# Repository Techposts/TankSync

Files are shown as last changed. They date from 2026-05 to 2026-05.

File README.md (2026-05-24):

# TankSync — reliable smart water monitoring






**Never worry about your water tank again.** A solar-powered sensor on the rooftop, a quiet hub on the wall, and smart water monitoring that keeps working — even when the internet doesn't. Long-range LoRa (RYLR998) to an ESP32 hub, local web UI, Home Assistant via HACS, optional cloud PWA. Open at the core.

<p align="center">
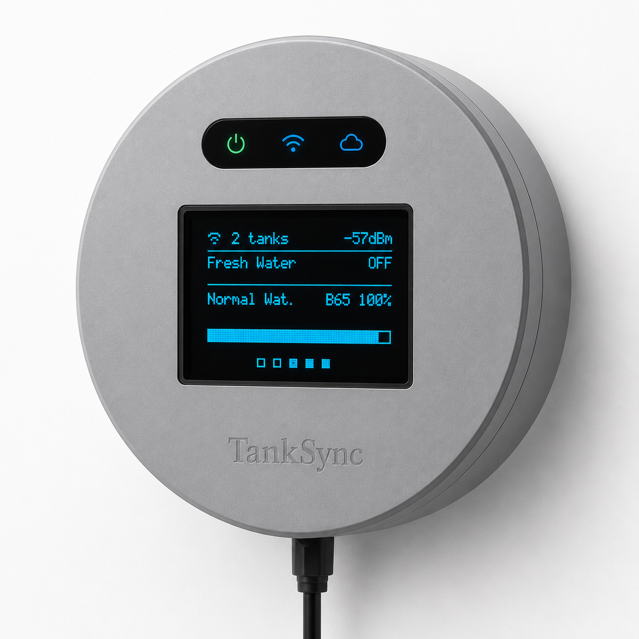
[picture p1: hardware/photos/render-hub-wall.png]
TankSync hub — wall-mounted, live OLED showing 2 tanks, status LEDs for power, WiFi, and cloud
  
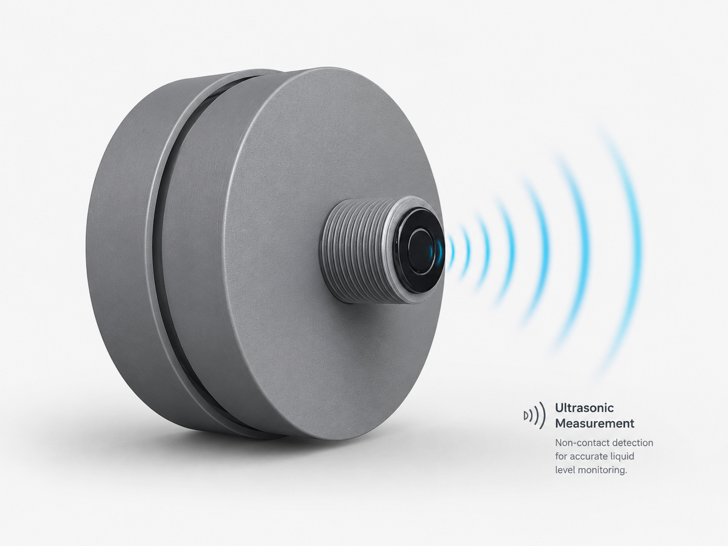
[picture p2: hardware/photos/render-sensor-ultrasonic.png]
TankSync solar tank sensor — side profile with ultrasonic measurement waves visualised
  
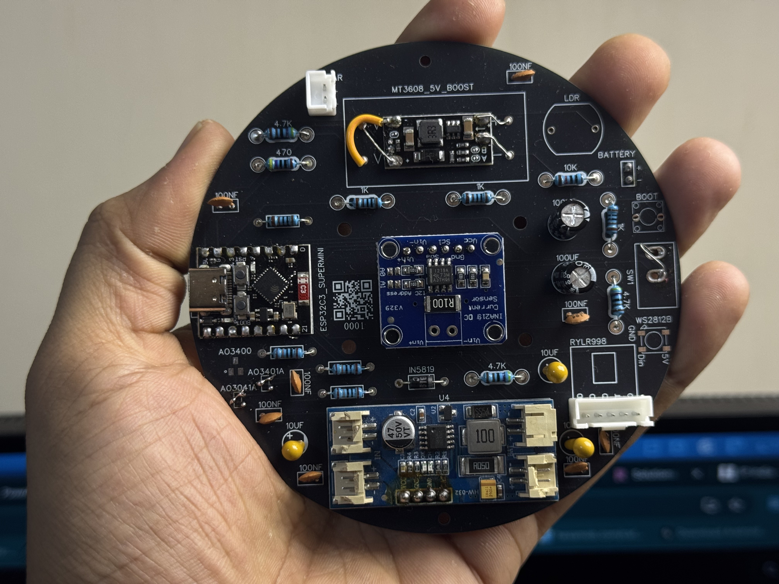
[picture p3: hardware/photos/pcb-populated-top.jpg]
Populated TX PCB — REV 2.2, May 2026 (open hardware)
  
</p>
<p align="center">
  <sub><em>The indoor hub (left), the solar tank sensor with non-contact ultrasonic measurement (centre), and the custom circular TX PCB (right) — current production hardware, REV 2.2 (May 2026), tested through Delhi summer at 45°C ambient.</em></sub>
</p>

## Try the in-browser flasher first

👉 **[tanksync.smartghar.org/firmware/](https://tanksync.smartghar.org/firmware/)**

No `esptool`, no Python, no CLI. Plug your board into USB, click Install, the browser does the flashing through WebSerial. Works on Chrome/Edge desktop. Takes ~45 seconds per board.

## Why TankSync — engineered to be reliable, not just smart

Most "smart tank" products treat the cloud as the product. TankSync treats **reliability** as the product — and the cloud as an optional layer of polish on top.

- **Works fully offline.** Hub keeps showing levels, lighting the LED ring, and beeping on overflow — even when your WiFi, your ISP, or our cloud is down. Local operation is the default; cloud is opt-in.
- **Long-range LoRa, no rooftop WiFi.** Sensor talks to the hub over 865 MHz LoRa — through concrete walls, between floors, across a property. Up to 5 km line-of-sight. The rooftop doesn't need WiFi. Ever.
- **Solar-powered transmitter.** Mounts on the tank lid. Charges in regular daylight, runs on a single 18650, deep-sleeps between readings. Months of autonomy. No wires to the tank.
- **Home Assistant native.** Auto-discovery via MQTT plus a dedicated [HACS integration](https://github.com/Techposts/smartghar-homeassistant) — every tank shows up as an HA device with live sensors, fill events, and editable settings.
- **Open at the core.** Firmware (AGPL-3.0), hardware (CC BY-SA 4.0), schematics, BOM, and flashing tools are all public. Self-host it. Fork it. Modify it. Audit it. No vendor lock-in.
- **Built for Indian realities.** Designed and tested through Delhi summer (45 °C ambient). UV-stabilised PETG, IP65 sealing, monsoon-ready. Engineered for terrace tanks, high-rise apartments, thick walls, and unreliable connectivity.

## Architecture

```
                    LoRa 865/915 MHz (up to 5 km, through walls)
                    ==============================================>
  TRANSMITTER                                          HUB (RECEIVER)
  ESP32-C3 SuperMini                                   ESP32 DevKit
  + JSN-SR04T Ultrasonic                               + RYLR998 LoRa
  + RYLR998 LoRa                                       + SH1106 OLED
  + 18650 + solar                                      + WS2812 LED ring
                                                       + WiFi (optional)
                                                          |
                                              +-----------+-----------+
                                              |                       |
                                       MQTT (TLS)              Local web UI
                                              |              192.168.x.x
                                    +---------+---------+
                                    |                   |
                              Home Assistant      Cloud dashboard
                              (HACS integration)  (optional, hosted)
```

## Hardware

| Component | Part | Approx cost (INR) |
|---|---|---|
| Receiver MCU | ESP32 DevKit v1 | ₹300–400 |
| Transmitter MCU | ESP32-C3 SuperMini | ₹200 |
| LoRa module | REYAX RYLR998 (×2) | ₹650 each |
| Ultrasonic sensor | JSN-SR04T (waterproof) | ₹350 |
| Display | SH1106 1.3" OLED I²C | ₹250 |
| Battery | Protected 18650 + holder | ₹200 |
| Solar charger | CN3791 MPPT module | ₹120 |
| Boost converter | MT3608 3.7 V → 5 V | ₹50 |

Total: **~₹3,800-5,200 per complete system** (one hub + one tank). Per-tank addition: ~₹1,500.

📐 **[Detailed wiring + power chains →](hardware/wiring.md)**
📋 **[Full BOM →](hardware/BOM.csv)**

## Quick start

### Option 1: Browser flasher (easiest — no install)

👉 **[tanksync.smartghar.org/firmware/](https://tanksync.smartghar.org/firmware/)**

Plug your board into a USB port, pick the right card (Receiver Hub or Transmitter), click Install. Done in ~45 sec.

### Option 2: esptool.py (CLI)

Download the latest `.bin` from [Releases](../../releases).

```bash
# Receiver (ESP32 DevKit)
esptool.py --chip esp32 -b 460800 write_flash 0x10000 tanksync-receiver-rx-vX.Y.Z.bin

# Transmitter (ESP32-C3 SuperMini)
esptool.py --chip esp32c3 -b 460800 write_flash 0x10000 tanksync-transmitter-tx-vX.Y.Z.bin
```

### Option 3: Build from source

Prerequisites: [ESP-IDF v5.4+](https://docs.espressif.com/projects/esp-idf/en/latest/esp32/get-started/)

```bash
# Receiver Hub
cd firmware/Receiver-ESP32-DevKit
idf.py build
idf.py -p /dev/ttyUSB0 flash

# Transmitter
cd firmware/Transmitter-IDF
idf.py set-target esp32c3
idf.py build
idf.py -p /dev/ttyACM0 flash
```

### First boot

1. **Hub** starts in AP mode → connect to `TankSync-XXXX` WiFi from your phone
2. Captive portal opens (or visit `192.168.4.1`)
3. Configure home WiFi + (optional) MQTT broker + LoRa settings

## What you'll use it through

Two surfaces — pick either, or both. They show the same data.

<p align="center">
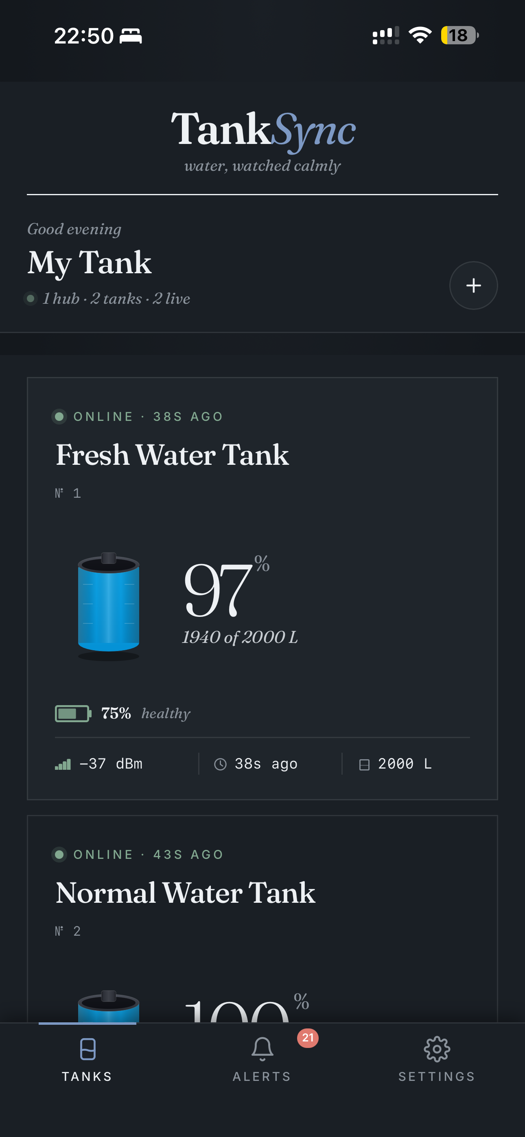
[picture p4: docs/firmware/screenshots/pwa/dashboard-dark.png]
TankSync PWA dashboard (phone)
  
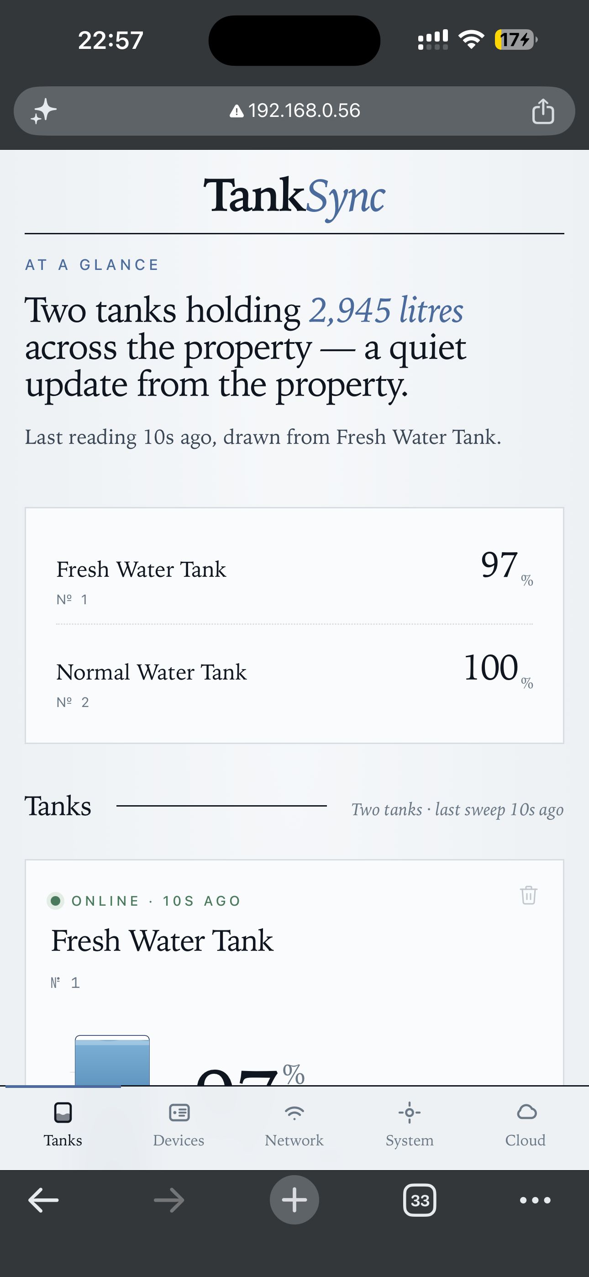
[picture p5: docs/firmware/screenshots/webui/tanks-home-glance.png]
Hub local web UI (any device on the same Wi-Fi)
  
</p>
<p align="center">
  <sub><em>Left: the PWA at <a href="https://tanksync.smartghar.org">tanksync.smartghar.org</a> — works from anywhere. Right: the hub's local web UI — works fully offline. Full walkthrough in the <a href="https://github.com/Techposts/TankSync/wiki">Wiki</a>.</em></sub>
</p>

4. **Transmitter** pairs over the air — hold its `BOOT` button for 2 sec, hub LED turns green when paired

## Photos of a real build

<p align="center">
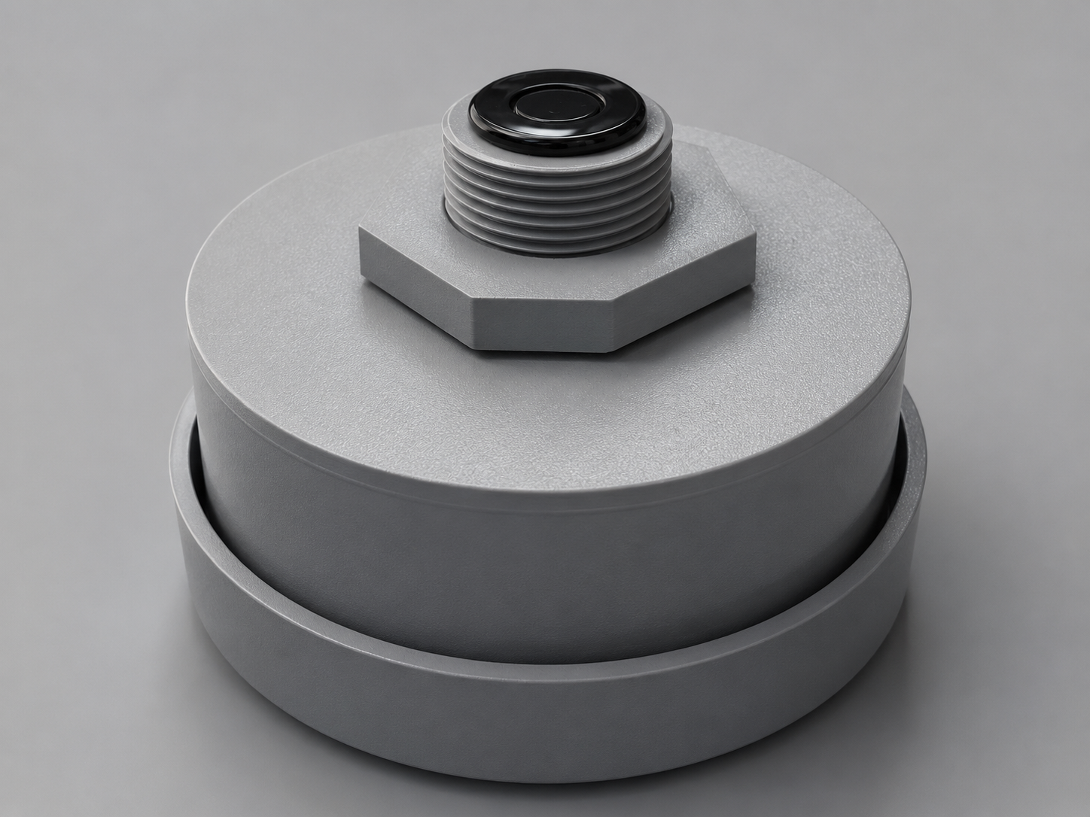
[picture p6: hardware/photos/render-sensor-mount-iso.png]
TankSync solar sensor — isometric render showing the BSP-threaded sensor boss + hex lock-nut
  
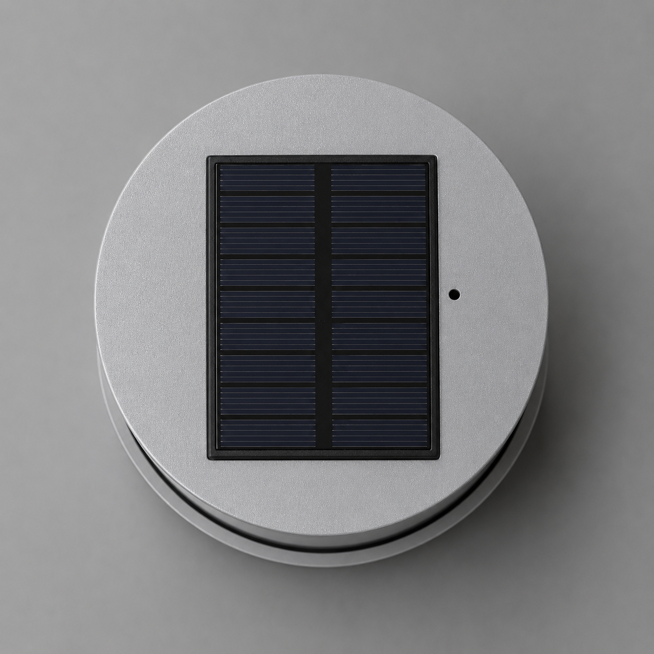
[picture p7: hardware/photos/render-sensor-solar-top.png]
TankSync solar sensor — top-down render showing the embedded solar panel
  
</p>
<p align="center">
  <sub><em>Renders of the production sensor — the threaded boss + hex lock-nut secure the sensor through a standard tank-lid hole; the solar panel sits flush on the case top.</em></sub>
</p>

<p align="center">
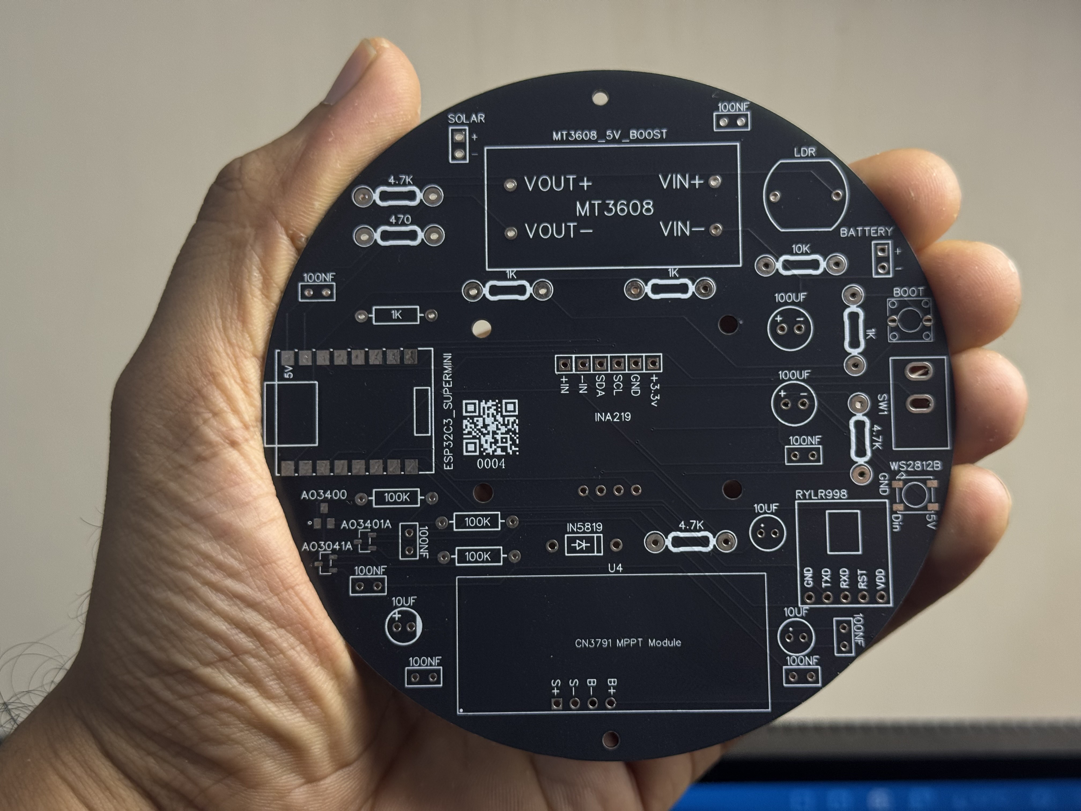
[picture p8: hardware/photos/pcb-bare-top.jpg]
Bare PCB, fresh from fab
  
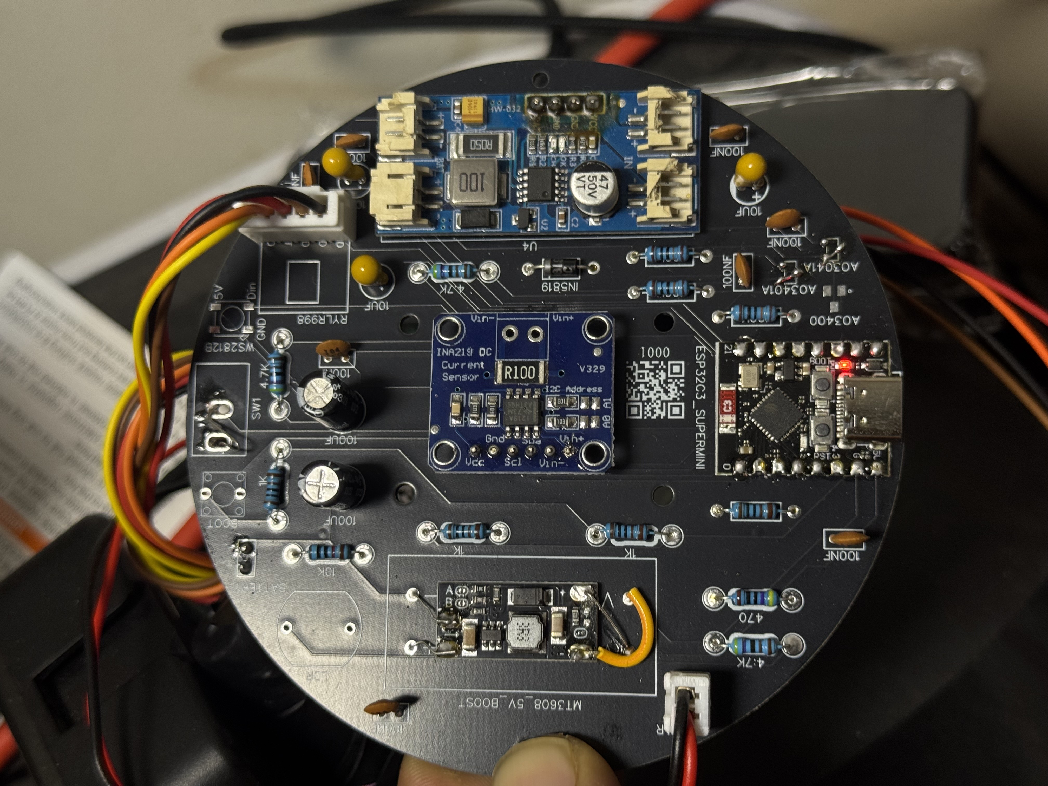
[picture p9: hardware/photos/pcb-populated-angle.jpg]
Populated PCB, angled view
  
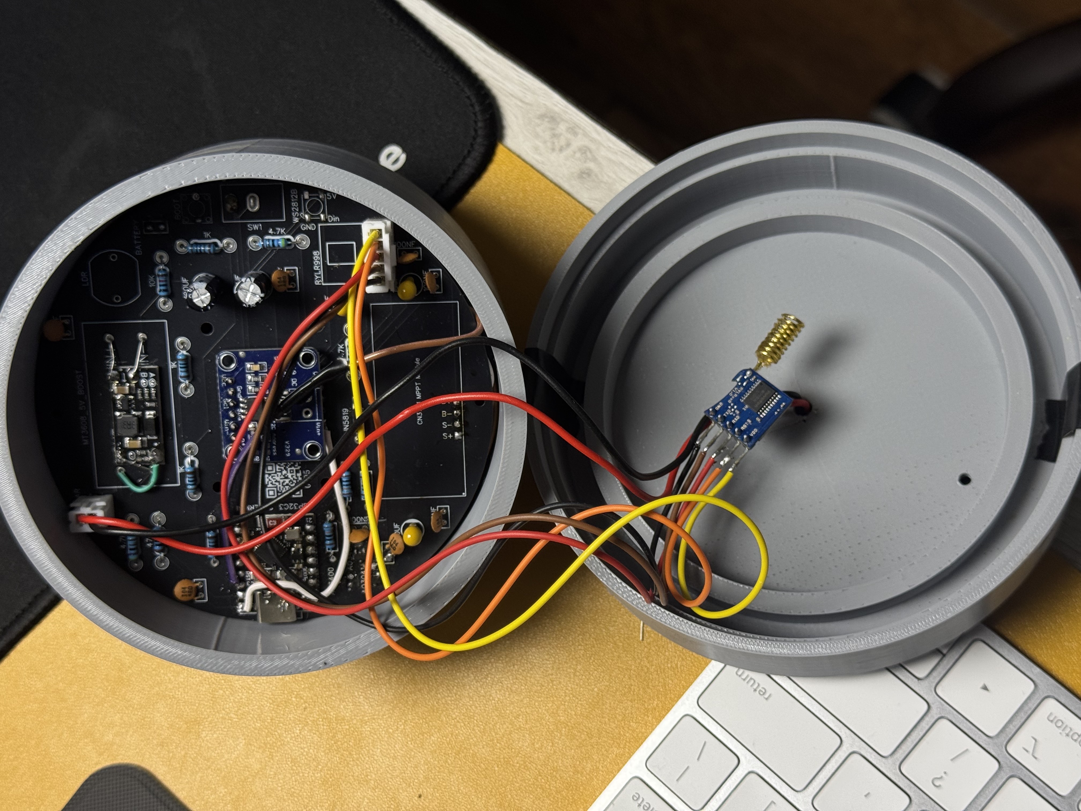
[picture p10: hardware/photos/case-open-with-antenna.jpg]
Opened case showing internals + antenna
  
</p>
<p align="center">
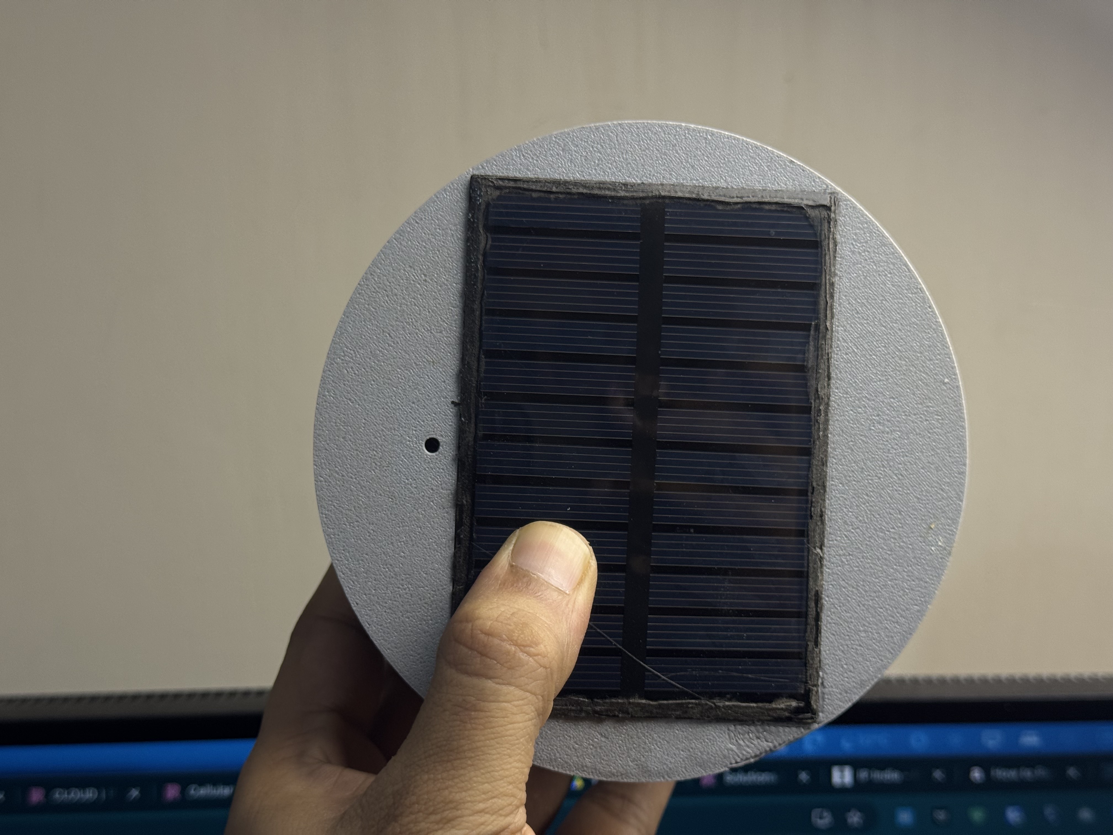
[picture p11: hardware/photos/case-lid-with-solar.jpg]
Lid with integrated solar panel pocket
  
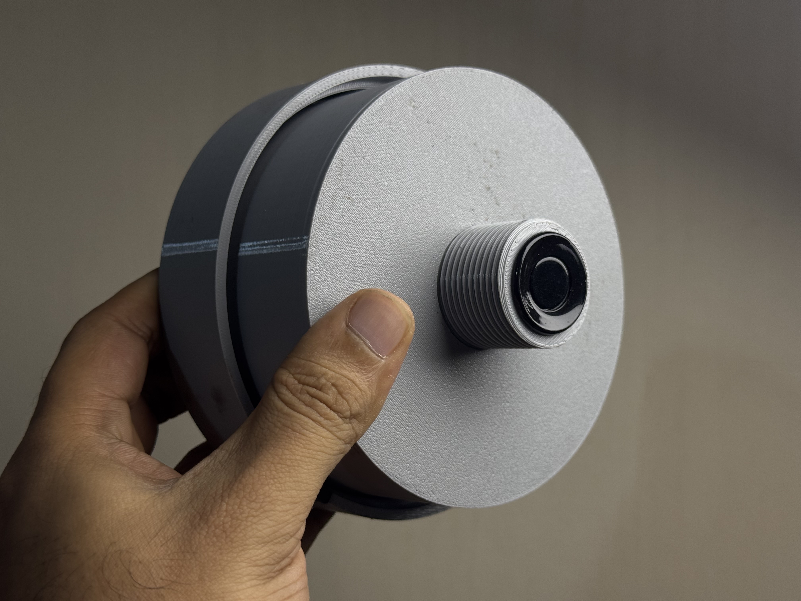
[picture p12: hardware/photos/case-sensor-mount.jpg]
BSP-threaded sensor mount on a test tank lid
  
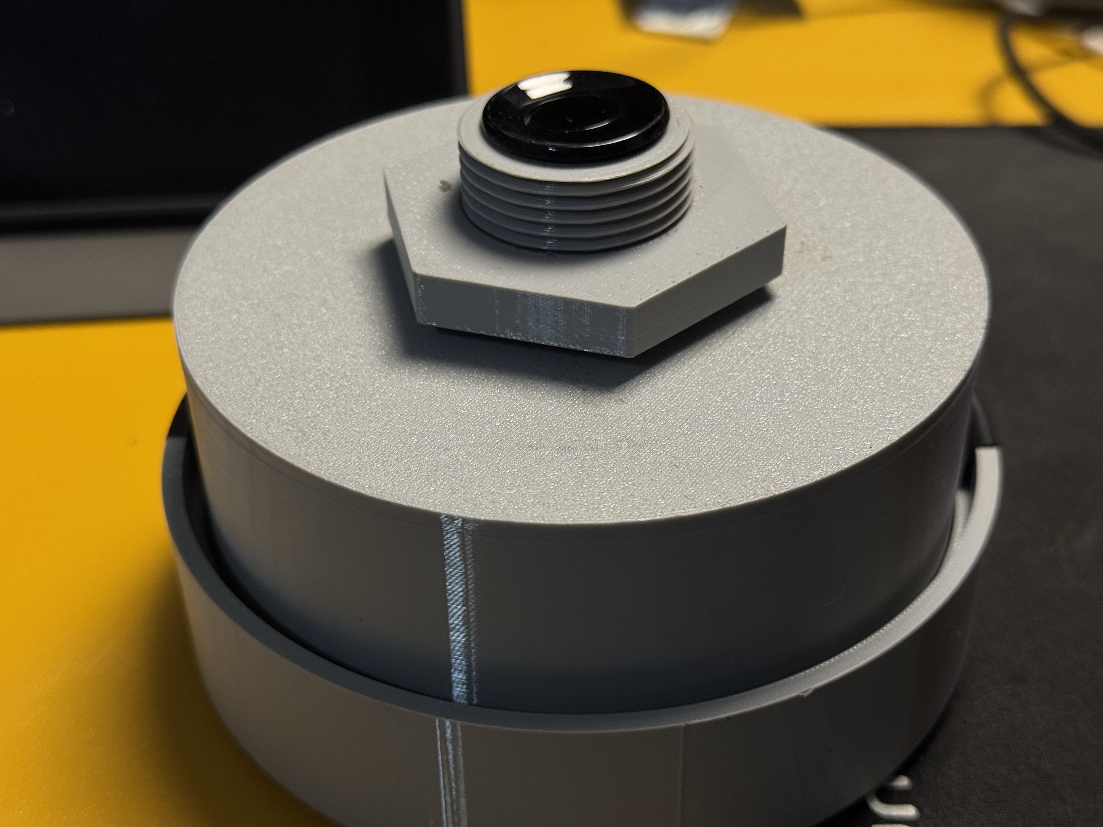
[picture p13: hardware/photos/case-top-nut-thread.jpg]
Close-up of the sensor-mount nut + thread
  
</p>

More photos + STL files for the case + schematics + 3D STEP models: **[hardware/](hardware/)**.

## Home Assistant integration

Two routes — pick whichever fits your setup:

1. **Native MQTT auto-discovery** — the hub publishes auto-discovery topics; tanks appear in HA as sensor entities with zero setup beyond pointing HA at the same broker. Read-only.
2. **HACS integration: SmartGhar** — full bidirectional control. Every tank is an HA device with grouped Sensors / Events / Configuration / Diagnostic entities, plus a hub device with buzzer + LED controls. **Capacity, sleep interval, samples-per-wake are editable from inside HA** and ride the same MQTT command channel as the PWA, so both stay in sync.

<p align="center">
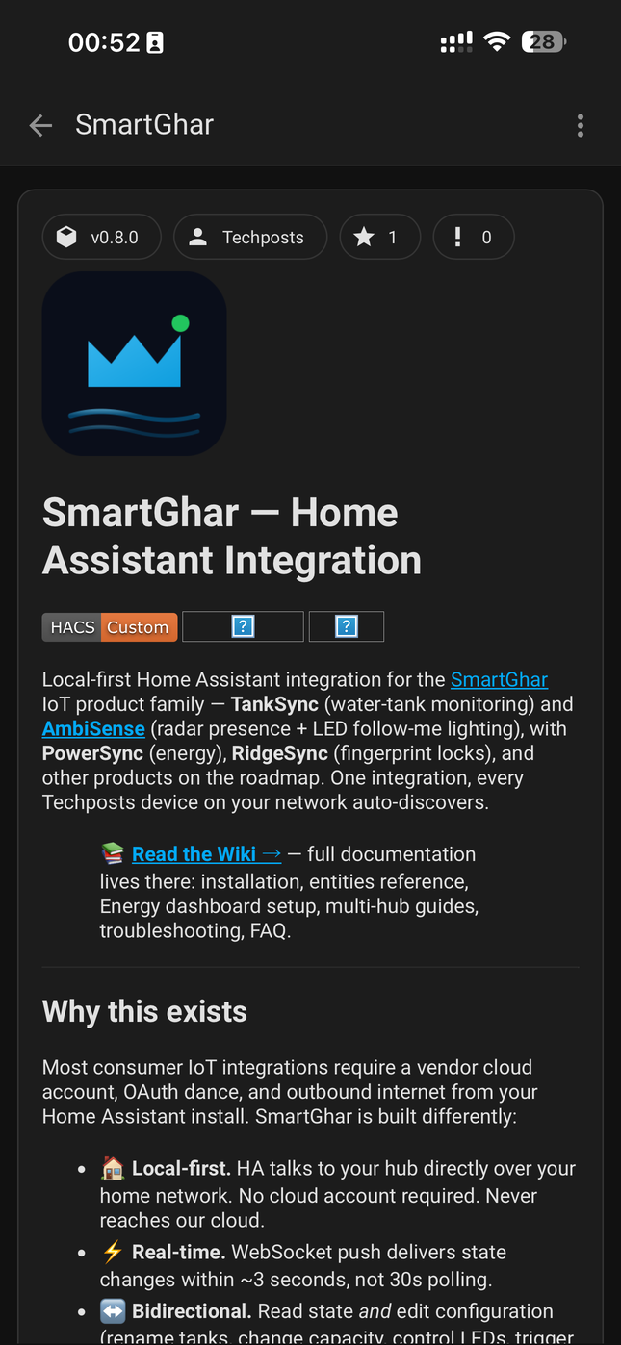
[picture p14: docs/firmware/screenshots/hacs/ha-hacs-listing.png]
HACS listing — SmartGhar v0.8.0
  
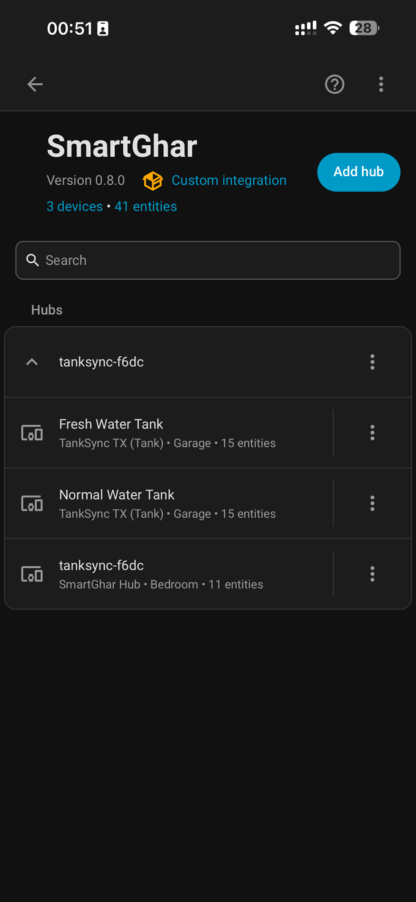
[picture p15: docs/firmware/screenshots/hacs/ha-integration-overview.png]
Integration overview — 3 devices, 41 entities
  
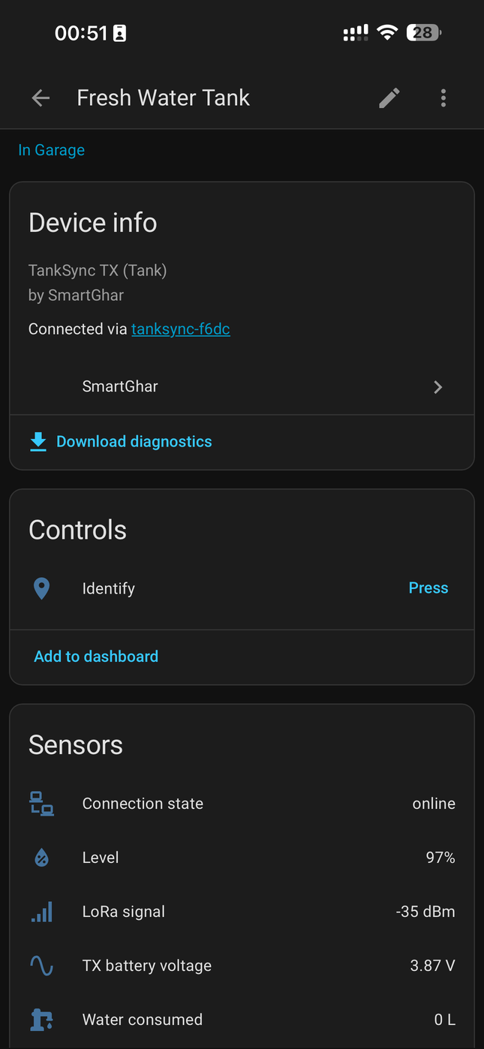
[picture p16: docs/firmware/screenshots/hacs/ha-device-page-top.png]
Tank device page — info + sensors
  
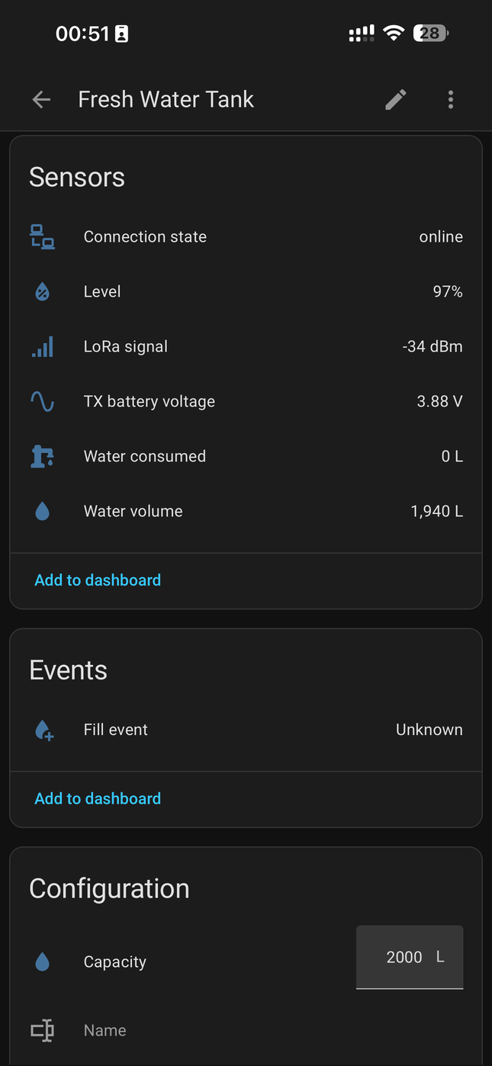
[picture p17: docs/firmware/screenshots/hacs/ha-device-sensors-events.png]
Sensors + Events + Configuration
  
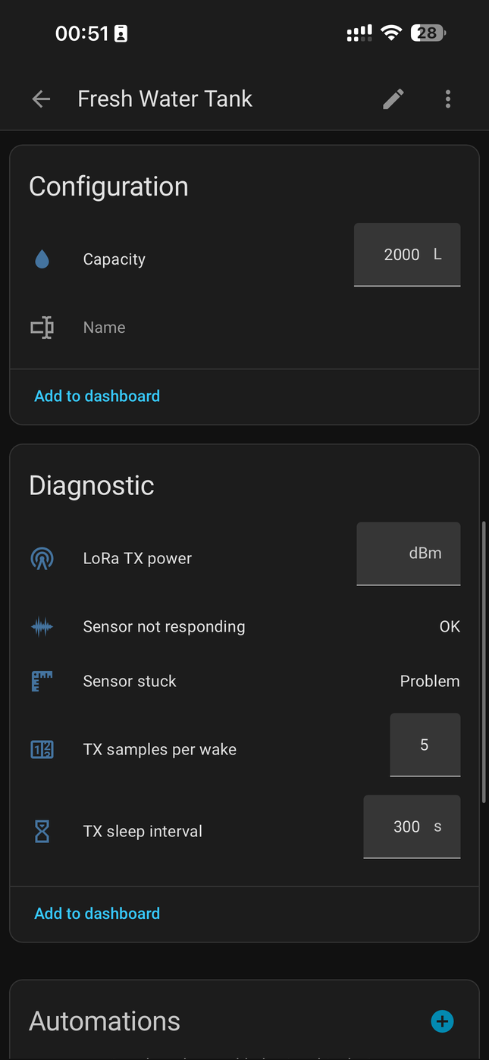
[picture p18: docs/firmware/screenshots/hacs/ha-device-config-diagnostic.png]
Configuration + Diagnostic — editable from HA
  
</p>

**HACS repo:** [github.com/Techposts/smartghar-homeassistant](https://github.com/Techposts/smartghar-homeassistant) · **Full setup + entity reference:** [HACS Integration wiki page](https://github.com/Techposts/TankSync/wiki/HACS-Integration)

## What's NOT in this repo (and why)

This is the open-source TankSync firmware + hardware mirror. The hosted cloud dashboard (PWA at [tanksync.smartghar.org](https://tanksync.smartghar.org)) is a separate **proprietary** product that adds:

- Remote access from anywhere (no port forwarding)
- Push notifications to your phone
- Multi-tank history + insights
- QR-code device linking
- Multi-hub fleet management for societies, farms, hotels

The firmware works fully **without** the cloud — local web UI on the hub gives you tank levels, settings, OTA updates, Home Assistant integration. Cloud is opt-in convenience, never a dependency.

## Licenses

| Component | License | What this means |
|---|---|---|
| Firmware (`firmware/`) | [AGPL-3.0](LICENSE) | Free for personal + community use. Commercial users who modify and distribute must also open-source their changes under AGPL. |
| Hardware (`hardware/`) | [CC BY-SA 4.0](hardware/LICENSE) | Attribution + ShareAlike. Build it, sell it, modify it — credit the source and share-alike. |
| HA Integration | [MIT](https://github.com/Techposts/smartghar-homeassistant/blob/main/LICENSE) (separate repo) | Frictionless for HA ecosystem. |

**Why AGPL on firmware?** It keeps TankSync open for hobbyists and HA users while preventing commercial vendors from repackaging the firmware into a closed product. If you want a non-AGPL commercial license for embedded use, reach out to the maintainer.

## Contributing

Issues and PRs welcome. Read the [wiring guide](hardware/wiring.md) before opening hardware-related issues.

## Author + brand

**Ravi Singh** ([@ravis1ngh on YouTube](https://www.youtube.com/@ravis1ngh)) — solo-building open-source home infrastructure in India under the **TechPosts Media** / **SmartGhar** banner. Design, firmware, hardware, PCB layouts, and 3D-printed enclosures — all done in-house.

**TankSync** is part of the **SmartGhar** ecosystem ([smartghar.org](https://smartghar.org)) — calm, local-first smart-home infrastructure engineered for real-world Indian deployments.

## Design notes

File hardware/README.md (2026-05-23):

# TankSync Hardware

> Open hardware reference for the **TankSync** LoRa water-tank monitor.
> All files in this `hardware/` tree are released under **CC-BY-SA 4.0** — you can build, modify, and resell them; derivative designs must stay open under the same license.
> Firmware is **AGPL-3.0** (see `firmware/`).

TankSync is two boards talking to each other:

| Board | Role | Power | Where it lives |
|---|---|---|---|
| **TX (Transmitter)** | Ultrasonic level sensor + LoRa uplink, one per tank | Solar + 18650 Li-ion | On / inside the tank lid |
| **RX (Receiver / Hub)** | LoRa gateway + Wi-Fi / MQTT bridge + OLED + LED strip | USB-C 5 V | Indoors, plugged into a wall adapter |

A single RX hub talks to up to **6 TX nodes** over 865 / 868 / 915 MHz LoRa (region-selectable in firmware). The RX publishes readings to a local MQTT broker or to the SmartGhar cloud — your choice.

---

## What's in this folder

| Path | What | Format |
|---|---|---|
| [`BOM.csv`](BOM.csv) | Complete bill of materials for both boards + the enclosure | CSV |
| [`pcb/`](pcb/) | Schematics (PNG + SVG), pin assignments, 3D STEP files, system block diagram | PNG / SVG / PDF / STEP |
| [`cases/circular-v1/`](cases/circular-v1/) | **Current** production case — circular PETG, integrated solar lid, BSP-threaded sensor mount | STL |
| [`cases/rectangular-v10/`](cases/rectangular-v10/) | **Legacy** v1.0 case — rectangular, older PCB form factor (kept for reference) | STL |
| [`photos/`](photos/) | Photos of the assembled PCB and finished case (9 images, see below) | JPG |

### Gallery (TX build)

| | |
|---|---|
| Bare PCB | Populated, top |
| Bare PCB, top side | Hand-soldered, top side |
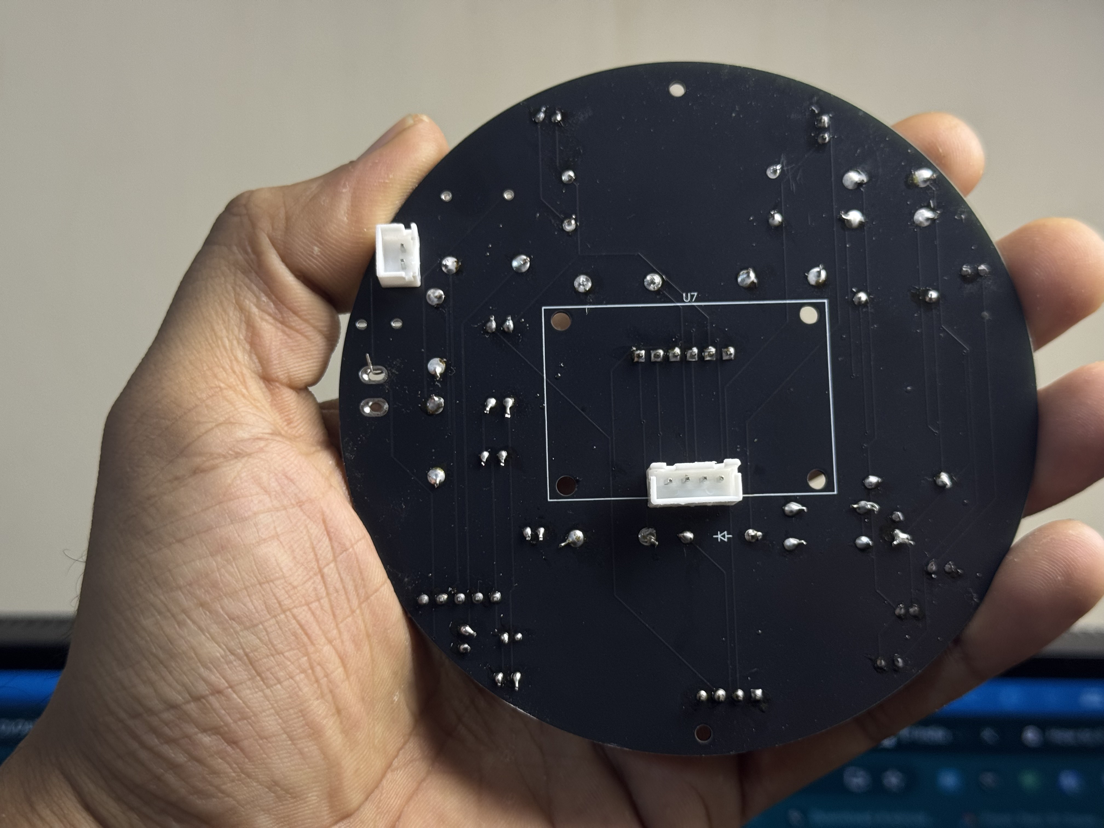
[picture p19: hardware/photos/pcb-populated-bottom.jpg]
Populated, bottom
|  | Populated, angle |
| Bottom side (passives + Schottky) | Angled view, modules stacked |
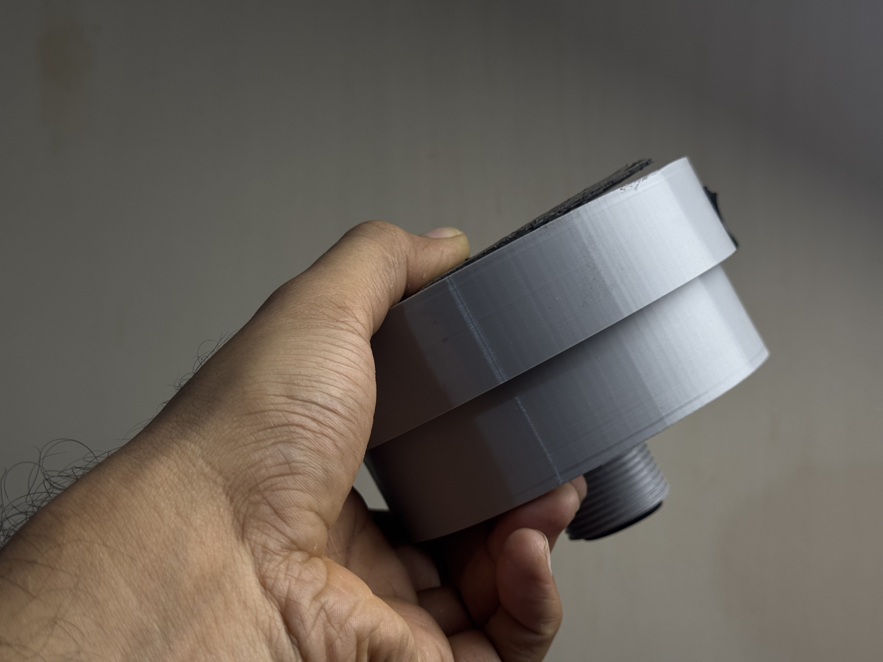
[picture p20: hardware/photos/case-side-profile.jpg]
Case side profile
| Lid with solar |  |
| Lid with integrated solar pocket | Closed assembly side view |
| Sensor mount | Top nut + thread |
| BSP boss in test tank lid | Close-up of nut + thread |
| Open with antenna | |
| Opened unit, SMA antenna variant | |

Each subfolder has its own `README.md` explaining what's inside and how to use it.

---

## Bird's-eye system diagram

```mermaid
flowchart LR
    TX[TX node<br/>solar + 18650] -->|LoRa 865 MHz| RX[RX hub<br/>USB-C]
    RX -->|Wi-Fi + MQTT| Broker[(MQTT broker<br/>local or cloud)]
    Broker --> HA[Home Assistant]
    Broker --> PWA[TankSync PWA]
```

All modules share a common ground. One TX per tank; one RX hub per property; up to 6 tanks per hub. Broker is either your local Mosquitto, or `mqtt.smartghar.org` if you use the free cloud tier.

---

## Quick start — I just want to build one

1. Print the case files from [`cases/circular-v1/`](cases/circular-v1/) (PETG, 0.2 mm, 30 % infill — see that folder's README).
2. Order parts from [`BOM.csv`](BOM.csv).
3. Get the PCBs fabbed from `pcb/rx-schematic.*` + `pcb/tx-schematic.*` (or send the project files to JLCPCB / PCBWay).
4. Solder, populate the BOM, then flash the firmware → easiest path is the **browser flasher** at [tanksync.smartghar.org/firmware](https://tanksync.smartghar.org/firmware) (Chrome / Edge desktop, USB-C cable, no toolchain install).
5. Power on the RX → connect to its `TankSync-Setup-XXXX` Wi-Fi AP → configure Wi-Fi + MQTT.
6. Hold the TX boot button 5 s → it joins the RX automatically via LoRa pairing mode.

The TankSync wiki has a step-by-step build guide: [github.com/Techposts/TankSync/wiki](https://github.com/Techposts/TankSync/wiki).

---

## Licensing

- **Firmware** (anything under `firmware/`) — AGPL-3.0
- **Hardware** (schematics, PCB layouts, STL cases, BOM, this folder) — CC-BY-SA 4.0
- **Brand** — "TankSync" and "SmartGhar" are trademarks of Ravi Singh / TechPosts Media; you can build and sell the open-hardware design but please don't use the brand names for commercial derivatives.

Patches welcome via pull request. If you ship a commercial product based on this design, the AGPL + CC-BY-SA terms require you to publish your modifications under the same license.

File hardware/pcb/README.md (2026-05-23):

# TankSync PCB Designs

Both boards were designed by **Ravi Singh** in EasyEDA — solo design work, no hardware team. The current production revision (**REV 2.2**, May 2026) has been **bench-tested at 45 °C ambient through Delhi summer** with no observable RYLR998 RSSI drift or boost-converter sag.

The TX is a **custom circular PCB** sized to drop straight into the [circular-v1 enclosure](../cases/circular-v1/). The RX is a **rectangular carrier** that sockets an ESP32 DevKit v1 (CP2102) module — no microcontroller redesign needed.

---

## Files in this folder

| File | What it is | When you need it |
|---|---|---|
| [`rx-schematic.png`](rx-schematic.png) / [`.svg`](rx-schematic.svg) | RX hub schematic | Read before populating the board |
| [`tx-schematic.png`](tx-schematic.png) / [`.svg`](tx-schematic.svg) | TX transmitter schematic | Read before populating the board |
| [`pin-assignments.md`](pin-assignments.md) / [`.pdf`](pin-assignments.pdf) | GPIO → function table for both boards | When firmware doesn't see a peripheral — check here first |
| [`system-block-diagram.pdf`](system-block-diagram.pdf) | One-page TX↔RX↔cloud overview | When explaining the system to someone new |
| [`rx-pcb-3d.step`](rx-pcb-3d.step) / [`tx-pcb-3d.step`](tx-pcb-3d.step) | 3D CAD models of the populated boards | If you're designing your own enclosure — import into Fusion / FreeCAD / OnShape |
| [`project-requirements.txt`](project-requirements.txt) | The original brief sent to PCBWay | Reference only — supersedes by the schematics + pin-assignments above |

---

## TX board (transmitter) — at a glance

- **MCU**: ESP32-C3 SuperMini (RISC-V, Wi-Fi + BLE, PCB antenna)
- **Radio**: REYAX RYLR998 LoRa module (UART AT-command, 865 / 868 / 915 MHz selectable)
- **Sensor**: JSN-SR04T / AJ-SR04M waterproof ultrasonic — connected via screw terminals so the sensor cable is field-installable
- **Power**: 18650 Li-ion + CN3791 MPPT solar charger + MT3608 3.3 V boost
- **Battery telemetry**: INA219 over I²C (current + voltage, signed) — replaced the older voltage-divider design in v1.0
- **Protection**: inline Schottky on the 18650 (+) rail; 1 k + 2 k divider on the 5 V ECHO line so the ECHO signal is safe for the C3's 3.3 V GPIO

### Power path

```mermaid
flowchart LR
    Panel[Solar panel<br/>~6V 1-2W] --> MPPT[CN3791 MPPT]
    MPPT --> Bat[18650 cell]
    Bat --> Boost[MT3608 boost]
    Boost --> C3[ESP32-C3 + RYLR998 + sensor]
```

All modules share a common ground. Vmpp tracking lands the panel near 4.5 V. The CN3791's BAT+ feeds the 18650 holder through an inline Schottky (SS14 / 1N5819) — destroyed two test boards before adding this.

### Signal path

```mermaid
flowchart LR
    C3[ESP32-C3<br/>SuperMini] <-->|UART1<br/>GPIO20/21| LoRa[RYLR998]
    C3 -->|TRIG<br/>GPIO4| Sens[JSN-SR04T]
    Sens -->|ECHO via 1k/2k div<br/>GPIO5| C3
    C3 <-->|I2C<br/>GPIO1/2| INA[INA219]
    C3 -->|WS2812 data<br/>GPIO7| LED[Status LED]
```

The full pin map is in [`pin-assignments.md`](pin-assignments.md) — that's the source of truth; if this diagram drifts, the table wins. Wire-by-wire detail also lives there.

---

## RX board (hub) — at a glance

- **MCU**: ESP32 DevKit v1 (Tensilica, Wi-Fi + BLE, USB-C onboard via CP2102)
- **Radio**: RYLR998 (same module as TX, same frequency, addresses differ)
- **Display**: 1.3" SH1106 OLED over I²C (status + Wi-Fi + IP + paired tanks)
- **LED strip**: WS2812B — user-selectable 2 / 8 / 24 LEDs, configured via the local web UI
- **Buzzer** (since rx-v2.8.0): active 3-pin piezo on GPIO 02 — audible nudges for low water, overflow, sensor errors
- **Power**: USB-C 5 V, 1 A nominal (5 W adapter is fine)

### Power path (RX)

```mermaid
flowchart LR
    USB[USB-C 5V] --> LDO[AMS1117-3.3]
    LDO --> ESP[ESP32 DevKit]
    LDO --> Lora[RYLR998 + OLED]
    USB -->|direct 5V<br/>+ 1000 µF cap| WS[WS2812B strip]
```

The WS2812B strip is on the **raw 5 V rail**, not the 3.3 V regulator output — a 24-LED ring at full white can draw >1 A, which would brown out the LDO. The 1000 µF inrush cap is critical.

### Signal path (RX)

```mermaid
flowchart LR
    ESP[ESP32 DevKit] <-->|UART2<br/>GPIO16/17| Lora[RYLR998]
    ESP <-->|I2C<br/>GPIO21/22| OLED[SH1106]
    ESP -->|WS2812 data<br/>GPIO13| WS[LED strip]
    ESP -->|Buzzer<br/>GPIO02| Buz[Piezo]
```

`GPIO 2` on the DevKit is taken by the **on-board LED**, which is why the **WS2812 data line is on GPIO 13**, not GPIO 2 — don't move it.

---

## Schematic reading tips (from review)

- The schematic PNG renders are correct but small; if you're hand-reviewing, open the SVG in a browser and zoom — the layer naming is preserved.
- The ECHO divider (TX) is on the PCB; do not omit it even if your sensor is rated for 3.3 V. JSN-SR04T variants in the wild differ on ECHO logic level, and the divider is cheap insurance.
- The I²C pull-ups on the TX board are populated as 4.7 kΩ. Some INA219 breakouts ship with their own pull-ups — if you use a breakout, remove or de-populate the on-PCB ones to avoid double pull-up.
- All decoupling caps (100 nF) belong **within 5 mm** of the IC power pin. The schematic shows them grouped for readability, but the layout enforces the distance.

---

## Critical things the firmware will refuse to boot without

1. **TX**: RYLR998 must answer `AT\r\n` at 115200 baud within 1.5 s. If wiring is reversed (TX↔RX swap), nothing pairs.
2. **RX**: SH1106 OLED must respond at I²C 0x3C. If absent or at 0x3D, the display stays blank but firmware otherwise runs — useful as a diagnostic.
3. **TX**: INA219 should answer at I²C 0x40. If absent, firmware falls back to voltage-divider battery monitoring on GPIO 0 (Variant A).

If you're hitting a boot loop, scope the UART RX line on either board first — most "the radio is dead" reports are reversed TX/RX wiring.

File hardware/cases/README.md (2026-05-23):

# TankSync Enclosures

Two case generations live here. **Print only the current revision unless you're explicitly building a legacy unit.**

| Folder | Status | PCB shape | Material | When to use |
|---|---|---|---|---|
| [`circular-v1/`](circular-v1/) | **Current — production** | Circular custom PCB | PETG | Always, for any new build |
| [`rectangular-v10/`](rectangular-v10/) | Legacy reference | Rectangular off-the-shelf carrier | PETG | Only if you already have v1.0 PCBs in inventory |

---

## Why two designs?

The original **rectangular v1.0** case was built around stacked off-the-shelf modules on a rectangular carrier — fine for the prototype, but the form factor wasn't ideal for the tank-lid mount, and the assembly involved many internal wires.

The **circular v1** is a ground-up redesign: a circular custom PCB sized to drop straight into the lid, with the ultrasonic sensor screw-mounted through a BSP-threaded boss, and an integrated solar-panel pocket on the top half. It was **tested through Delhi summer (45 °C ambient)** for thermal stability — the PETG holds shape, the panel doesn't delaminate, and the gasket compresses reliably.

The rectangular STL is kept here purely as reference for anyone who already fabbed those PCBs.

---

## Printing notes (shared across both designs)

- **Material**: PETG. *Not* PLA — sun + 45 °C summer = sag. *Not* ABS unless you've got an enclosure printer with good ventilation. ASA also works.
- **Layer height**: 0.2 mm structural / 0.16 mm cosmetic
- **Infill**: 30 % gyroid (good stiffness-to-weight + survives compression on screw-down)
- **Walls**: 4 perimeters minimum — strength matters more than print speed for outdoor parts
- **Supports**: needed on the sensor screw and (for circular-v1) the lid-with-solar piece. See per-design README for tree-vs-grid hint.
- **Brim**: 5 mm — PETG warp is real on first layer if the bed is below 80 °C
- **Bed**: 80–90 °C; nozzle 240–250 °C
- **Outdoor seal**: every case is designed to clamp a 1–2 mm EPDM gasket between lid and body. The screw torque does the sealing — don't skip the gasket if the tank is outdoors.

See `../../docs/hardware/printing-guide.md` (work in progress) for tested slicer profiles.

---

## Choosing between PETG colours

Black PETG runs hotter under sun (measured ~5 °C above ambient). The TX has thermal margin — 45 °C ambient + 5 °C tint + 5 °C internal dissipation = within the 18650's 65 °C derating. But if you live somewhere genuinely hot (Rajasthan summer, north Australia), **print white or light-grey** for the lid. The base can stay any colour you like.

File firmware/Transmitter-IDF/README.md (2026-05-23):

# TankSync Transmitter (ESP-IDF v2)

ESP32-C3 SuperMini battery-powered transmitter for the LoRa Water Tank Monitor.

## Hardware

- **MCU**: ESP32-C3 SuperMini (4MB flash, RISC-V single-core)
- **LoRa**: RYLR998 module (868/915 MHz)
- **Sensor**: AJ-SR04M ultrasonic distance sensor
- **Power**: LiPo battery with deep sleep (~300s cycle)

### Pin Configuration

| Function | GPIO | Notes |
|---|---|---|
| LoRa TX | 21 | UART1 TX to RYLR998 RXD |
| LoRa RX | 20 | UART1 RX from RYLR998 TXD |
| LED | 8 | On-board LED (C3 SuperMini) |
| Button | 9 | Boot button (active low, internal pullup) |
| Ultrasonic TRIG | 4 | AJ-SR04M trigger |
| Ultrasonic ECHO | 5 | AJ-SR04M echo |
| Battery ADC | 0 | Voltage divider (1:2 ratio) |

## Boot Window

On **power-on or reset** (NOT timer wake), the TX opens a 10-second boot window. LED blinks at 1Hz. Hold the button for:

| Hold Duration | Action | LED Feedback |
|---|---|---|
| 2 seconds | **Pairing mode** — broadcasts PAIR_REQ via LoRa | 6 rapid flashes |
| 5 seconds | **Diagnostic mode** — prints system info to serial | Steady on |
| 8 seconds | **WiFi OTA mode** — creates WiFi AP for firmware update | 10 rapid flashes |

Timer wakes from deep sleep skip the boot window entirely (battery savings).

## Firmware Update Methods

### Method 1: WiFi AP OTA (Recommended for deployed devices)

1. Press **reset** on the transmitter
2. During the 10s boot window, **hold the button for 8 seconds**
3. LED flashes rapidly to confirm — TX creates WiFi AP: **`TankSync-Update`**
4. Connect your phone/laptop to the `TankSync-Update` WiFi network (open, no password)
5. Open a browser and go to **`http://192.168.4.1`**
6. The web page shows:
   - **Device Info** — current firmware version, LoRa address, sleep/sample settings
   - **Settings** — edit sleep interval and sample count, save directly to NVS
   - **Firmware Update** — select a `.bin` file and upload with progress bar
7. After successful upload, the TX verifies the binary and reboots
8. If no activity for 5 minutes, TX auto-reboots to normal mode

**Status**: WiFi AP starts and serves the page. OTA upload handler is implemented. Needs end-to-end testing.

### Method 2: LoRa OTA (Experimental — pushed from receiver)

The receiver can push firmware updates to the transmitter over LoRa during the TX's downlink window.

**Protocol**:
1. Receiver stages TX firmware binary on SPIFFS via web UI
2. When TX wakes and sends TANK data, receiver sends `OTA_START:<size>` (3x for reliability)
3. Both sides switch to SF7/500kHz for faster chunk streaming
4. TX sends `OTA_READY` (3x), enters chunk receive loop
5. Receiver streams 100-byte chunks as hex-encoded `OTA_DATA:<offset>:<hex>`
6. TX ACKs each chunk with `OTA_ACK:<next_offset>`
7. After all chunks: `OTA_END` / `OTA_DONE` exchange, TX reboots

**Status**: Partially working. Chunks are delivered at SF7/500kHz (~260ms per chunk, 23x faster than SF9/125kHz). However, ~40% ACK packet loss causes the transfer to stall after 6-30 chunks. The half-duplex nature of LoRa means the receiver can't receive ACKs while transmitting chunks.

**Known Issues**:
- ACK reliability: TX sends OTA_ACK but receiver misses ~40-50% due to half-duplex timing
- OTA_READY often lost (worked around with soft wait + proceed anyway)
- At SF9/125kHz, chunk airtime is 1050ms creating a large half-duplex blind window
- At SF7/500kHz, airtime drops to ~45ms but packet loss persists at lower rates

**Potential fixes** (contributions welcome):
- Blast mode: skip per-chunk ACK, stream all chunks with fixed delay, verify at end
- Adaptive retry with exponential backoff
- Reduce chunk size to minimize airtime
- Use address 0 (broadcast) for chunks to bypass address filtering edge cases

### Method 3: USB Serial (Development only)

```bash
cd Transmitter-IDF
. ~/esp/esp-idf/export.sh
idf.py -p /dev/cu.usbmodem12201 flash
```

## Building

```bash
cd Transmitter-IDF
. ~/esp/esp-idf/export.sh    # or wherever your ESP-IDF is installed
idf.py set-target esp32c3
idf.py build
```

**Important**: After `set-target`, the sdkconfig may re-enable WiFi. The custom partition table and flash size are set in `sdkconfig.defaults`.

## Version Management

Two version strings must be kept in sync:
- `main/config.h` → `FIRMWARE_VERSION` (used in TANK packets and logs)
- `CMakeLists.txt` → `PROJECT_VER` (embedded in binary `esp_app_desc_t`, read by receiver for OTA display)

## Partition Table

```
nvs,      data, nvs,      0x9000,   0x5000
otadata,  data, ota,      0xe000,   0x2000
app0,     app,  ota_0,    0x10000,  0x1D0000  (1.8MB)
app1,     app,  ota_1,    0x1E0000, 0x1D0000  (1.8MB)
coredump, data, coredump, 0x3B0000, 0x10000
```

Current firmware size: ~860KB (with WiFi AP OTA) / ~263KB (without). Both fit within the 1.8MB partition.

## NVS Keys

| Namespace | Key | Type | Description |
|---|-----|---|---|
| `system` | `sleep_s` | u32 | Sleep interval in seconds (default: 300) |
| `system` | `samples` | u8 | Sensor samples per reading (default: 5) |
| `lora` | `my_addr` | u16 | Device LoRa address (set during pairing) |
| `lora` | `rx_addr` | u16 | Receiver's LoRa address (default: 2) |
| `lora` | `freq` | u32 | LoRa frequency in Hz |
| `lora` | `netid` | u8 | Network ID |
| `lora` | `sf` | u8 | Spreading factor (7-12) |
| `lora` | `bw` | u8 | Bandwidth (7=125kHz, 8=250kHz, 9=500kHz) |
| `lora` | `pwr` | u8 | TX power (0-22 dBm) |

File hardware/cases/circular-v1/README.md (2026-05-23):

# Circular v1 Enclosure — Current Production

Production case as of **May 2026**. Designed for the circular custom PCB documented in [`../../pcb/`](../../pcb/). Tested through Delhi summer (45 °C ambient) — PETG holds shape, integrated solar pocket doesn't delaminate, EPDM gasket compresses reliably for IP65 sealing.

---

## STL files

| File | What it is | Print orientation |
|---|---|---|
| [`base-holder.stl`](base-holder.stl) | Bottom shell — holds the PCB + 18650 holder | Flat side down, no supports inside the cavity |
| [`top-with-solar.stl`](top-with-solar.stl) | Top lid with integrated solar-panel pocket | Solar pocket facing up, **tree supports** on the underside of the lip |
| [`sensor-screw.stl`](sensor-screw.stl) | BSP-threaded boss the JSN-SR04T screws through | Threads up; supports on the gland-side flange |
| [`nut.stl`](nut.stl) | Locking nut that mates with the sensor-screw boss from inside the tank lid | Flat down, no supports |

Print all four for a complete unit.

---

## Bill of additional parts

In addition to the PCB BOM ([`../../BOM.csv`](../../BOM.csv)):

| Item | Spec | Where it goes |
|---|---|---|
| Solar panel | 6 V, 1–2 W, 60–80 mm matching the lid pocket | Sits in the top-with-solar pocket; wires through small grommet |
| EPDM gasket | 1–2 mm × 60 mm OD circular, NBR also OK | Between base and lid |
| M3 stainless screws | 4×, 12 mm length | Lid → base, through gasket |
| M3 stainless threaded inserts (optional) | Heat-set, 4× | Base — for stronger repeated open/close |
| Cable gland | M12 PA66 IP65, 4–6 mm cable range | Bottom of base — sensor cable exit |
| BSP thread (sensor mount) | Matches `sensor-screw.stl` threads | Field-drilled into the tank lid |

---

## Assembly sequence (TLDR)

1. Heat-set M3 inserts into the four corners of `base-holder.stl` (if using).
2. Drop the populated TX PCB into the base; align mount holes; tape the 18650 holder in place.
3. Feed the sensor cable through the cable gland from outside, leaving slack inside. Screw-terminal both ends to the PCB.
4. Mount the panel into the lid pocket; thread its wires through the small grommet; solder to the PCB's panel input.
5. Place the EPDM gasket on the base rim. Screw the lid down with the four M3 stainless screws — moderate torque (~1 Nm). The gasket compresses to ~50 % thickness.
6. The `sensor-screw.stl` + `nut.stl` mount on the **tank lid itself**, with the JSN-SR04T head facing down into the tank. Apply Teflon tape on the BSP threads for water seal.

A photo-by-photo build guide is in the wiki: [github.com/Techposts/TankSync/wiki/Hardware-Build](https://github.com/Techposts/TankSync/wiki/Hardware-Build).

---

## Design notes

- The lid solar pocket is **slightly oversize** to allow a 1 mm silicone bead around the panel for UV sealing. Don't pour epoxy — it traps heat against the panel.
- The sensor-screw boss is intentionally tall (~20 mm) so the JSN-SR04T transducer head sits clear of the tank lid's internal surface. Lid-touching sensors give phantom echoes from the lid material.
- The PETG print is rated for outdoor use, but **direct UV will yellow it over years**. If you care about aesthetics long-term, add a 1 mm clear-coat or use ASA.
- IP65 was the design target — tested with light rain + hose spray. Not tested under submersion (and the tank shouldn't ever submerge the TX anyway).

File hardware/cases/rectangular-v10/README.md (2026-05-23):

# Rectangular v1.0 Enclosure — Legacy

Original prototype case used during TankSync v1.0. **Kept here for reference only.** New builds should use [`../circular-v1/`](../circular-v1/) — that's the current production design.

You only want this folder if:

- You already fabbed rectangular v1.0 PCBs and have inventory to use up, or
- You're studying the design evolution for your own project.

---

## STL files

| File | What it is |
|---|---|
| [`main-body.stl`](main-body.stl) | Bottom shell of the original rectangular enclosure |
| [`top-lid.stl`](top-lid.stl) | Top lid (no solar pocket — this design had an external panel) |
| [`tpu-gasket.stl`](tpu-gasket.stl) | Printable TPU gasket (alternative to a die-cut EPDM gasket) |
| [`sensor-screw.stl`](sensor-screw.stl) | Sensor mount — matches the v1.0 sensor-cable layout |
| [`bolt-screw.stl`](bolt-screw.stl) | Captive screw used to clamp lid to body in the v1.0 design |

---

## Why it's legacy

The rectangular v1.0 case worked, but had drawbacks the circular v1 redesign solved:

1. **Form factor** — rectangular footprint doesn't match how most tank lids are shaped (round threaded openings), so mounting required adapters.
2. **Solar panel** — external, wired in through a grommet. Two more failure points (UV-aging cable + grommet seal).
3. **Assembly time** — more internal wiring (stacked modules on a rectangular carrier, vs the circular custom PCB which integrates everything).
4. **Print time** — larger XY footprint means longer prints.

The TPU printable gasket worked fine but most builders switched to die-cut EPDM (more consistent compression, cheaper at >10 units).

For any new build use [`../circular-v1/`](../circular-v1/).

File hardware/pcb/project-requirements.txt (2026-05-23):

PROJECT TITLE
TankSync v1.0 — Solar LoRa water-tank monitor: outdoor TX + indoor RX hub for Indian homes

PROJECT REQUIREMENTS

A two-board IoT product. Hardware bench-validated on dev kits with working open-source firmware (github.com/Techposts/tanksync). I need PCBWay to convert proven pin assignments and bench wiring into manufacturable PCBs + matching enclosures + sample units.

A) TX (Tank Transmitter) — outdoor, solar-powered, mounts on overhead/sump tanks. Reads water level via ultrasonic sensor; sends readings via LoRa to indoor hub. Deep-sleeps between wakes for battery life.

B) RX (Receiver / Hub) — indoor, USB-C powered. Receives LoRa from up to 6 paired TX, drives OLED + LED ring, bridges to cloud via WiFi/MQTT, hosts local web UI.

----------------------------------------------------------------------
1. PCB DESIGN REQUIREMENTS
----------------------------------------------------------------------

FUNCTIONAL REQUIREMENTS

TX Board:
- Read distance via ultrasonic sensor (JSN-SR04T / AJ-SR04M, waterproof)
- Sense battery + solar power via INA219 (I2C) and ADC voltage divider (variant)
- Charge 18650 Li-ion from solar via CN3791 MPPT + boost converter to 3.3V
- Communicate with RX over LoRa (RYLR998 module, UART)
- Deep-sleep between wake cycles (default 60s, configurable to 5–60 min)
- Status LED + tactile BOOT button (5s hold = AP mode for re-pairing)

RX Board:
- Receive LoRa packets from up to 6 TX units
- Drive 1.3" SH1106 OLED (I2C) for live tank levels
- Drive WS2812B LED chain (2 / 8 / 24 LEDs) for ambient indication
- Connect to home WiFi, publish telemetry to MQTT broker
- Host a local HTTP server for configuration (port 80)
- USB-C input, BOOT/RESET buttons accessible

INPUT/OUTPUT INTERFACES

TX:
- Screw terminal (2-pin) for ultrasonic sensor cable (field-installable, NOT pre-crimped at factory — sensor cable length varies by tank)
- Screw terminal or barrel jack (2-pin) for solar panel input
- 18650 battery holder
- Tactile BOOT + RESET buttons through enclosure window
- Status LED visible through enclosure window
- USB-C for development flashing

RX:
- USB-C for power + flashing
- 3-pin connector for WS2812B LED strip (5V, GND, DATA)
- 4-pin I2C header for SH1106 OLED (3.3V, GND, SDA, SCL) — display can be onboard or off-board
- BOOT + RESET tactile buttons accessible
- RYLR998 LoRa module on header (SMA antenna optional, PCB-edge whip default)

PERFORMANCE REQUIREMENTS

TX:
- MCU: ESP32-C3 SuperMini (RISC-V, 160 MHz, integrated WiFi/BT, PCB antenna)
- LoRa link: 865 MHz (India ISM band) at 22 dBm, SF7-12 configurable
- Active current: <5 mA during a wake cycle (~1.5 s of sensor read + LoRa transmit)
- Deep sleep current: <50 µA average over 60s sleep cycle
- Sensor accuracy: ±1 cm at 30 cm – 4 m range (JSN-SR04T spec)
- Battery life target: >12 months in clean Indian sun on a 1.5W panel

RX:
- MCU: ESP32 DevKit (Tensilica, 240 MHz, WiFi + BT)
- LoRa: same as TX
- I2C: 100 kHz standard mode (OLED + future I2C peripherals)
- WiFi: 2.4 GHz station mode + AP mode (for setup)
- LED refresh: 30 Hz typical, supports inrush spikes up to 1 A briefly

DIMENSIONS AND PHYSICAL SPECIFICATIONS

TX board: target ~50 × 50 mm, 1.6 mm FR-4, 4 corner mounting holes (M2.5).
RX board: target ~70 × 50 mm, 1.6 mm FR-4, 4 corner mounting holes (M2.5).
Both boards must fit inside their respective enclosures with cable routing margins.

POWER REQUIREMENTS

TX: 18650 Li-ion battery (3.0 – 4.2 V). Solar input 5 – 7 V, max 1 A. CN3791 MPPT charges battery; boost converter delivers 3.3 V regulated to ESP32-C3. Reverse-polarity Schottky diode required inline on battery + (we have lost test boards by reversing the holder). Total system current must be <100 µA during deep sleep (no quiescent draw from boost beyond MCU).

RX: USB-C 5 V / 1 A nominal input. LDO to 3.3 V for ESP32 + LoRa. WS2812B chain runs from 5 V rail directly. 1000 µF bulk cap on the 5 V rail near the LED data input — WS2812B can pull >1 A briefly when all LEDs go to white at full brightness (power-on flash, attention modes).

COMPATIBILITY REQUIREMENTS

- ESP32-C3 SuperMini and ESP32 DevKit modules are off-the-shelf parts; ours uses the standard pinouts. We need carrier boards that mount these modules (NOT redesigned MCUs — module-on-carrier is fine and is what the prototypes use).
- RYLR998 is the chosen LoRa module (UART, 865 MHz). Do not substitute without consulting us — firmware is tied to RYLR998 AT command set.
- JSN-SR04T / AJ-SR04M ultrasonic — interchangeable, both have a 4-pin header (VCC, GND, TRIG, ECHO). 5V powered, 5V echo output — voltage divider (1k + 2k to GND) on ECHO line is required because ESP32-C3 GPIOs are NOT 5V tolerant.
- INA219 at I2C 0x40 (default jumper config), 0.1 Ω shunt. Auto-detected by firmware.
- SH1106 1.3" OLED at I2C 0x3C, 128×64.

RELIABILITY

- Service life: 5+ years
- TX: -10°C to +60°C, IP65, monsoon + dust + coastal salt-haze
- RX: 0°C to +45°C, normal humidity
- Antenna keep-out: >5 mm clear copper around RYLR998 + ESP32-C3 antennas
- Decoupling: 100 nF + 10 µF within 5 mm of every IC

----------------------------------------------------------------------
2. ENCLOSURE DESIGN REQUIREMENTS
----------------------------------------------------------------------

TX ENCLOSURE (outdoor)
- IP65+ protection (rated for monsoon rain + rooftop dust + summer 45°C)
- Material: UV-stabilised ABS or polycarbonate (NOT plain ABS — degrades in Indian sun within 18 months)
- Cable glands: 2 (one for ultrasonic sensor cable, one for solar panel cable), M12 thread, sized for 4–6 mm cable
- Battery access: removable cover with captive screws, gasket-sealed
- Mounting tabs: 4 outside the seal, accept standard tank-lid bracket screws
- Window: small clear/translucent window for status LED visibility
- Buttons: BOOT + RESET as panel-mount tactile with rubber boots (waterproof)
- Approximate size: 80 × 80 × 40 mm internal cavity (final size depends on PCB layout + battery orientation)
- Ergonomic: must mount easily on a tank lid, no sharp edges

RX ENCLOSURE (indoor)
- IP20 (dust ingress only, no water resistance needed)
- Material: ABS or PC, smooth/matte finish acceptable
- Form factor: desktop or wall-mount, reversible hanging holes
- Window: clear cutout for OLED (or transparent panel covering whole top face)
- LED diffuser: cutout for WS2812B strip with frosted-acrylic lens or print-in-place diffuser
- USB-C port access: cutout aligned with onboard USB-C connector
- Buttons: cutouts for BOOT + RESET (recessed pin-press is fine, no rubber boots needed indoors)
- Approximate size: 100 × 60 × 30 mm
- Aesthetic: minimalist, inspired by editorial/calm UI design (the matching app uses light/serif design language)
- Colour: white or warm grey for primary; brand logo placement on top face (we will provide the logo SVG)

INTERFACE AND OPENING REQUIREMENTS

TX cutouts:
- 2 cable glands (M12)
- 1 battery cover (gasketed)
- 1 LED window (3–5 mm)
- 2 button windows (rubber-booted tactile)

RX cutouts:
- 1 OLED window (~30 × 18 mm visible area)
- 1 LED strip cutout (12 × 20 mm or strip-shaped depending on 2/8/24 chosen)
- 1 USB-C port (rectangular)
- 2 button cutouts (recessed)

----------------------------------------------------------------------
3. SOFTWARE / FIRMWARE
----------------------------------------------------------------------

We have working firmware (open-source, github.com/Techposts/tanksync). PCBWay does NOT need to write firmware — please verify your schematic against our firmware's pin assignments before fab. Pin tables are provided in the attached "pin-assignments" PDF.

Reprogramming methods supported:
- USB (CP2102 USB-UART for RX, ESP32-C3 native USB-CDC for TX)
- OTA over WiFi (cellular OTA via cloud MQTT bridge — already shipped in current firmware)

----------------------------------------------------------------------
4. ENVIRONMENTAL TESTING REQUIREMENTS
----------------------------------------------------------------------

TEST OBJECTIVES

Validate that both TX and RX prototypes meet the operating-environment specs before approving for production.

ENVIRONMENTAL PARAMETERS

TX (outdoor):
- Temperature: -10°C to +60°C operating, soak test at +50°C for 4h
- Humidity: 10% to 95% RH non-condensing
- IP65 spray test per IEC 60529 (low-pressure water from any direction, 3 minutes)
- Dust ingress test: dust chamber 8h
- UV exposure: 100h accelerated (equivalent to ~1 year Indian rooftop)

RX (indoor):
- Temperature: 0°C to +45°C operating
- Humidity: 30% to 70% RH

TEST SAMPLES

2 of each board (TX + enclosure, RX + enclosure) — 4 sample units total.

PASS/FAIL CRITERIA

- Functional: pairing succeeds, LoRa link >-110 dBm at 100 m line-of-sight, OLED renders our test pattern, LED chain cycles through colours, OTA over WiFi completes
- Battery: TX active <5 mA, deep sleep <50 µA
- Mechanical: IP65 holds during spray, no water ingress on TX seal

----------------------------------------------------------------------
5. WHAT WE PROVIDE
----------------------------------------------------------------------

- Pin assignments PDF (attached)
- Working firmware, open-source
- Confirmed BOM with part numbers (attached CSV)
- System block diagram PDF (attached)
- Bench-prototype photos (attached)

Open to your component substitutions where they reduce cost without changing function — flag any in the quote. Budget is flexible if quality justifies it.

Volume: 100 – 500 kits in first 12 months (Indiegogo + direct). BOM target: $15 – $22 per unit.

Contact: support@smartghar.org — SmartGhar / TechPosts Media.

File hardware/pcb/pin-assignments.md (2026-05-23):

# TankSync v1.0 — Pin Assignments Reference

Extracted verbatim from working firmware (`firmware/Receiver-ESP32-DevKit/main/config.h` and `firmware/Transmitter-IDF/main/config.h`). These are the **canonical** pin assignments. The schematic must match this table. If the schematic deviates, the firmware will fail at boot.

---

## TX Board — ESP32-C3 SuperMini

The TX is the outdoor solar-powered tank sensor. Carrier board accepts an **ESP32-C3 SuperMini module**; do not substitute the MCU.

| GPIO | Function | Connects to | Direction | Notes |
|---|---|---|---|---|
| **GPIO 21** | LORA_TX (UART1) | RYLR998 RXD | Output | 3.3 V logic level |
| **GPIO 20** | LORA_RX (UART1) | RYLR998 TXD | Input | 3.3 V logic level |
| **GPIO 8** | On-board status LED | LED through resistor | Output | Active-high (built into module) |
| **GPIO 7** | WS2812B data | WS2812B chain (2 LEDs in series for TX) | Output | 5V level via level shifter optional; works at 3.3 V if WS2812B is forgiving |
| **GPIO 4** | Ultrasonic TRIG | JSN-SR04T / AJ-SR04M TRIG | Output | 3.3 V — sensor is 5V powered but TRIG is fine at 3.3 V |
| **GPIO 5** | Ultrasonic ECHO | Voltage divider → JSN-SR04T ECHO | Input | **5V echo MUST be divided** (1k + 2k = 1.65 V at ECHO=5V) |
| **GPIO 9** | BOOT button | Tactile button → GND, INPUT_PULLUP | Input | 5s hold = AP mode for re-pairing |
| **GPIO 0** | Battery ADC (Variant A) | 100k + 100k divider from VBAT | Analog input | Variant A only (voltage-divider battery monitoring) |
| **GPIO 1** | I²C SDA | INA219 SDA | I/O | Variant B (INA219-based power telemetry) |
| **GPIO 2** | I²C SCL | INA219 SCL | Output | Variant B |

### TX power-path schematic (text)

```
Solar panel (+)  →  Schottky  →  CN3791 MPPT input
Solar panel (-)  →  GND
CN3791 BAT+      →  18650 holder (+)  via reverse-polarity Schottky inline
CN3791 BAT-      →  18650 holder (-)  →  GND
18650 (+)        →  Boost converter  →  3.3 V rail  →  ESP32-C3 SuperMini
                                       ↘  RYLR998 VCC
                                       ↘  Sensor 5V (via boost-to-5V or direct)
INA219 in series with battery (+) — measures both charge and discharge current.
ESP32-C3 GPIO0 reads battery voltage via 100k + 100k divider (Variant A) OR
ESP32-C3 reads INA219 over I²C at GPIO1/GPIO2 (Variant B). Auto-detects.
```

Both variants share the same firmware binary; only the BOM differs (Variant A uses 2× 100k resistors and a small cap; Variant B uses an INA219 module). Carrier should support both — populate one variant, leave the other footprints unpopulated.

---

## RX Board — ESP32 DevKit (38-pin)

The RX is the indoor USB-C-powered hub. Carrier board accepts an **ESP32 DevKit v1 (CP2102)** — 38-pin module with USB-C onboard. Module is socketed; do not redesign.

| GPIO | Function | Connects to | Direction | Notes |
|---|---|---|---|---|
| **GPIO 16** | LORA_RX (UART2) | RYLR998 TXD | Input | 3.3 V logic level |
| **GPIO 17** | LORA_TX (UART2) | RYLR998 RXD | Output | 3.3 V logic level |
| **GPIO 13** | WS2812B data | WS2812B strip (2 / 8 / 24 LEDs) | Output | **GPIO 2 is taken by onboard LED** — DO NOT use GPIO 2 for the strip |
| **GPIO 21** | I²C SDA | SH1106 OLED SDA | I/O | Standard ESP32 I²C SDA |
| **GPIO 22** | I²C SCL | SH1106 OLED SCL | Output | Standard ESP32 I²C SCL |

### RX power-path schematic (text)

```
USB-C 5V  →  bulk filter cap (10 µF + 100 nF)  →  AMS1117-3.3 LDO
                                                  ↘  3.3 V rail  →  ESP32 DevKit (3V3 pin)
                                                                  ↘  RYLR998 VCC
                                                                  ↘  SH1106 OLED VCC
USB-C 5V  →  WS2812B VCC  (with 1000 µF inrush cap close to strip)
GND       →  common ground plane
```

WS2812B runs at 5 V directly (NOT through the 3.3 V rail); this is critical for LED brightness + colour accuracy. The 1000 µF cap absorbs inrush when all LEDs go to white at full brightness simultaneously (~1 A spike).

---

## Critical PCB constraints (please verify on layout review)

- **Antenna keep-out**: >5 mm clear copper around RYLR998 SMA pad AND around the ESP32-C3 PCB antenna. We have measured RSSI degradation when copper is closer.
- **ECHO voltage divider**: TX GPIO 5 reads ECHO from a 5V sensor. Must have a 1k–2k divider on-PCB. ESP32-C3 is NOT 5V tolerant.
- **Decoupling**: every IC needs 100 nF (within 5 mm) + 10 µF (within 10 mm). Especially RYLR998 — radio modules are noise-sensitive.
- **WS2812B inrush cap**: 1000 µF electrolytic close to the LED strip's 5V input, before any in-line resistor. Reduces brown-out risk.
- **Reverse-polarity**: 18650 input on TX MUST have an inline Schottky diode. We have destroyed test boards by reversing the holder.
- **Ground plane**: keep solid pour under both digital and analog sections. Stitching vias around the antenna keep-out.

---

## What firmware will check at boot

1. I²C scan at 0x40 — if found, INA219 mode (Variant B). If not, voltage divider mode (Variant A).
2. I²C scan at 0x3C (RX only) — must succeed for OLED rendering.
3. UART2 (RX) / UART1 (TX) probe — sends `AT\r\n` to RYLR998 at 115200 baud, waits for `+OK\r\n`. If no response, falls back to setup mode.

If the schematic uses different pins for any of the above, the firmware will not boot correctly. Please align the schematic to this table; do not change pin assignments without consulting us.

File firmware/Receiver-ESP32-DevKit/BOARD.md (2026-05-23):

# TankSync Receiver — ESP32 DevKit v1 (CP2102)

## Board: ESP32-WROOM-32 DevKit v1
- **Chip**: ESP32 dual-core Xtensa LX6 @ 240MHz
- **Flash**: 4MB
- **RAM**: ~320KB SRAM
- **USB**: CP2102 USB-Serial
- **Cores**: 2 (eliminates single-core UART/I2C contention issues from ESP32-C3)

## Pin Mapping

| Function | GPIO | Notes |
|---|---|---|
| LoRa TX (→ RYLR998 RXD) | 17 | UART2 TX |
| LoRa RX (← RYLR998 TXD) | 16 | UART2 RX |
| WS2812B LED Data | 13 | GPIO2 is onboard LED, avoid |
| OLED SDA | 21 | Standard I2C |
| OLED SCL | 22 | Standard I2C |
| Buzzer (active) | 2 | Shares onboard blue LED — LED pulses with buzzer. **Strapping pin: disconnect buzzer wire before USB flashing** (held-low at boot blocks ROM bootloader). OTA flashing unaffected. |

### Buzzer wiring

Active 3-pin buzzer module (the kind sold as "active buzzer module" — has on-board oscillator):

```
ESP32 DevKit              Buzzer module
------------              -------------
GPIO2        ------>      I/O  (signal)
3.3V         ------>      VCC
GND          ------>      GND
```

If you use a passive buzzer instead (no on-board oscillator), the firmware's
plain GPIO toggle won't drive it — passive buzzers need PWM at the resonant
frequency (typically 2 kHz). Swap `buzzer.c::buzz_on/off()` to use LEDC if needed.

**Flashing caveat**: GPIO2 is a strapping pin. If the buzzer holds the line
low at boot, the chip enters download mode and won't run firmware. For USB
flashing: disconnect the buzzer signal wire from GPIO2 first, then reconnect
after flash completes. OTA (over-WiFi) flashing is unaffected — the chip
re-reads strapping pins only at hard reset, not on OTA reboot.

## Wiring: RYLR998 LoRa Module

```
ESP32 DevKit          RYLR998
-----------          --------
GPIO17 (TX2) ------> RXD
GPIO16 (RX2) <------ TXD
3.3V         ------> VDD
GND          ------> GND
```

## Wiring: SH1106 OLED (optional)

```
ESP32 DevKit          SH1106 OLED
-----------          -----------
GPIO21 (SDA) ------> SDA
GPIO22 (SCL) ------> SCL
3.3V         ------> VCC
GND          ------> GND
```

## Wiring: WS2812B LEDs (optional)

```
ESP32 DevKit          WS2812B
-----------          -------
GPIO13       ------> DIN
5V           ------> VCC
GND          ------> GND
```

## Build & Flash

```bash
cd "Receiver-ESP32-DevKit"
export IDF_PATH=/path/to/esp-idf
. $IDF_PATH/export.sh
idf.py set-target esp32
idf.py build
idf.py -p /dev/cu.SLAB_USBtoUART flash monitor
```

## Key Differences from ESP32-C3 Build

| Feature | ESP32-C3 (Receiver-IDF) | ESP32 DevKit (this) |
|---|---|---|
| Cores | 1 (RISC-V) | 2 (Xtensa LX6) |
| UART for LoRa | UART1 (GPIO20/21) | UART2 (GPIO16/17) |
| I2C pins | GPIO9/10 | GPIO21/22 |
| INT WDT | Disabled (systimer bug) | Enabled (300ms) |
| CPU freq | 160MHz | 240MHz |
| USB | USB-Serial/JTAG (native) | CP2102 (external) |
| Serial port | /dev/cu.usbmodemXXXXX | /dev/cu.SLAB_USBtoUART |

## Why ESP32 DevKit?

The ESP32-C3 rev 0.4 has hardware issues:
1. `systimer_ll_is_counter_value_valid` busy-loops during interrupts → INT WDT crash
2. Single-core means UART/I2C/WiFi all compete for CPU → livelocks during OTA
3. I2C bus recovery can lock the APB bus → hard freeze

The ESP32 dual-core eliminates all three issues.

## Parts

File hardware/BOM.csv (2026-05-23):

Board | Designator | Description | Qty | Package | Mfr Part / Generic | Notes
TX | U1 | ESP32-C3 SuperMini module | 1 | Module (header pins) | ESP32-C3 SuperMini (generic, e.g. https://www.aliexpress.com/item/1005006453829627.html) | RISC-V MCU + WiFi/BT + PCB antenna; widely available
TX | U2 | RYLR998 LoRa module | 1 | Module (4-pin header) | REYAX RYLR998 | UART AT-command LoRa; 865 MHz IN / 868 MHz EU / 915 MHz US
TX | U3 | INA219 current/voltage sensor | 1 | SOIC-8 or breakout | Adafruit-style INA219 breakout OR raw chip | I2C @ 0x40 with 0.1 Ω shunt — Variant B only
TX | U4 | CN3791 MPPT solar charger | 1 | Breakout / SOP-8 | CN3791 MPPT module (5V tracking) | Charges 18650 from solar panel; tracks Vmpp ≈ 4.5 V
TX | U5 | 3.3V boost converter | 1 | SOT-23-6 or breakout | MT3608 or TPS61023 | Boosts 18650 (3.0–4.2V) to 3.3V regulated for ESP32-C3
TX | SENS1 | JSN-SR04T / AJ-SR04M ultrasonic | 1 | External (cable + screw terminals) | JSN-SR04T waterproof | 5V powered; sensor cable field-installable (NOT pre-crimped)
TX | BAT1 | 18650 Li-ion holder | 1 | Through-hole or PCB mount | Keystone 1042 or generic | Single 18650 cell holder
TX | J1 | Solar panel input | 1 | 2-pin screw terminal or barrel jack | Phoenix MKDS 1.5 or DC-005 | Field-wired to ~6V 1-2W panel
TX | J2 | Sensor cable | 1 | 2-pin screw terminal | Phoenix MKDS 1.5 | Field-wired to JSN-SR04T (length varies by tank)
TX | D1 | Schottky reverse-polarity protection | 1 | SOD-123 | SS14 or 1N5819 | Inline on 18650 (+) — protects against reversed cell
TX | D2 | Status LED | 1 | 3mm or SMD 0805 | Generic green LED | Visible through enclosure window
TX | SW1 | BOOT button | 1 | Tactile through-hole | 6mm tactile w/ rubber boot | Panel-mount; 5s hold = AP mode
TX | SW2 | RESET button | 1 | Tactile through-hole | 6mm tactile w/ rubber boot | Panel-mount; recessed
TX | R1-R2 | Voltage divider for ECHO | 2 | 0805 | 1k + 2k | Resistive divider on ECHO line (5V → 1.65V for ESP32-C3 GPIO 5)
TX | R3-R4 | Voltage divider for battery (Variant A) | 2 | 0805 | 100k + 100k | 1:2 divider for ADC battery monitoring (Variant A only)
TX | C1-C8 | Decoupling caps (100 nF) | ~8 | 0603 | Generic ceramic | One per IC near power pin
TX | C9-C12 | Bulk caps (10 µF) | ~4 | 0805 or 1206 | Generic electrolytic | One per IC + boost output
TX | C13 | Inrush cap on WS2812B 5V | 1 | Electrolytic radial | 470 µF / 16V | Smooths the 2 onboard LEDs
RX | U1 | ESP32 DevKit v1 (38-pin) | 1 | Module socketed | AZ-Delivery / DOIT ESP32 DevKit v1 (CP2102 USB-UART) | 240 MHz Tensilica MCU + WiFi/BT + onboard USB-C
RX | U2 | RYLR998 LoRa module | 1 | Module (4-pin header) | REYAX RYLR998 | Same as TX
RX | U3 | SH1106 1.3" OLED display | 1 | Module (4-pin I2C) | Generic SH1106 128x64 OLED 1.3 inch white | I2C @ 0x3C; through-hole 4-pin header
RX | U4 | WS2812B LED strip / ring | 1 | External | Generic WS2812B | User-selectable 2 / 8 / 24 LEDs (configurable via NVS)
RX | J1 | USB-C power input | 1 | USB-C onboard (on DevKit) | Built into DevKit module | 5V / 1A nominal
RX | J2 | WS2812B 3-pin connector | 1 | JST-XH 3-pin | JST-XH-3 | 5V / GND / DATA — to external LED strip
RX | J3 | OLED 4-pin connector (alternate) | 1 | 2.54mm header 4-pin | Generic | Alternative if OLED is off-board
RX | SW1 | BOOT button | 1 | Tactile | Generic 6mm tactile | Recessed (indoor — no rubber boot needed)
RX | SW2 | RESET button | 1 | Tactile | Generic 6mm tactile | Recessed
RX | C1 | Inrush cap on WS2812B 5V rail | 1 | Electrolytic radial | 1000 µF / 16V | **Critical** — absorbs >1A spike when all LEDs flash white
RX | C2-C9 | Decoupling caps (100 nF + 10 µF) | ~8 | 0603/0805 | Generic ceramic + electrolytic | One per IC near power pin
TX+RX | Antenna | Antenna | 1 each | SMA or PCB-edge | SMA bulkhead OR PCB whip | RYLR998 default = PCB whip; SMA optional for external
ENCLOSURE | Cable glands | 2 | Cable glands | M12 thread | Generic IP65 PA66 black | Sized for 4-6 mm cable diameter (TX only)
ENCLOSURE | Gasket | 1 | Battery cover gasket | EPDM/NBR | Generic | Compresses on screw-down for IP65 seal (TX only)
ENCLOSURE | Mounting screws | 4 | M3 stainless | Generic | Outdoor-rated for tank-lid bracket (TX only)

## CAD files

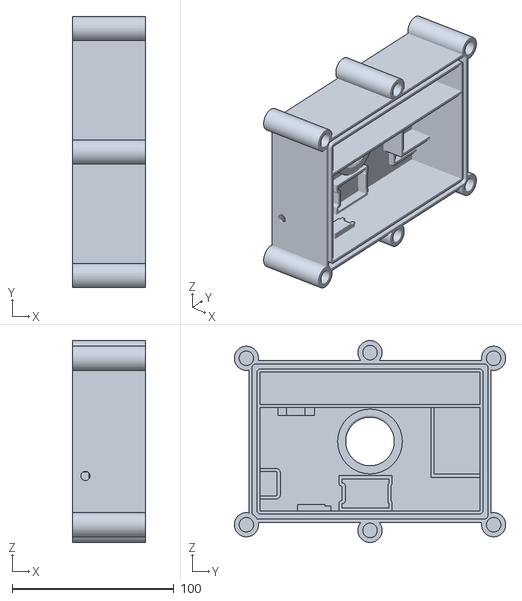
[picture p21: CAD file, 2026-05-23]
hardware/cases/rectangular-v10/main-body.stl
45.0 x 168.0 x 125.0

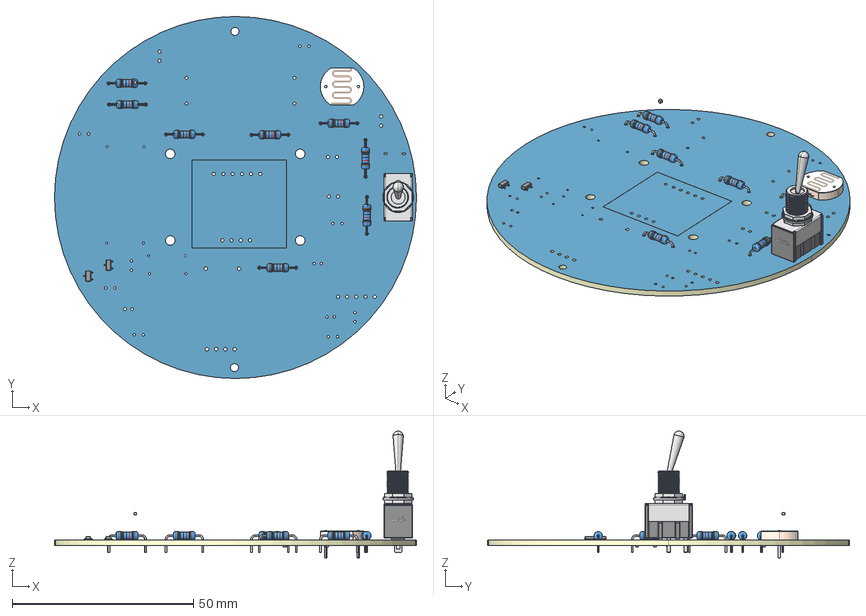
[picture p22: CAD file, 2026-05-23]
hardware/pcb/tx-pcb-3d.step
100.0 x 100.0 x 35.0 mm
Board~ZkP4
TopCopper~ZkP4
BottomCopper~ZkP4
TopFpcStiffener~ZkP4
BottomFpcStiffener~ZkP4
100K~RES_10K-0.25W~RES_10K-0.25W~ZkP4 x 4
SOT-23-3_L2.9-W1.4-P1.90-LS2.5-BR~SOT-23-3_ L2.9-W1.4-P1.90-LS2.5-BR~ZkP4 x 2
RESISTOR_0.25W~R_AXIAL-0.4~ZkP4 x 8
RES-TH_L12.0-W10.3-P9.00-D0.7~RES-TH_L12.0-W10.3-P9.00-D0.7~ZkP4
MT3608~MT3608~ZkP4
SW-TH_MTS-101~SW-TH_MTS-101~ZkP4

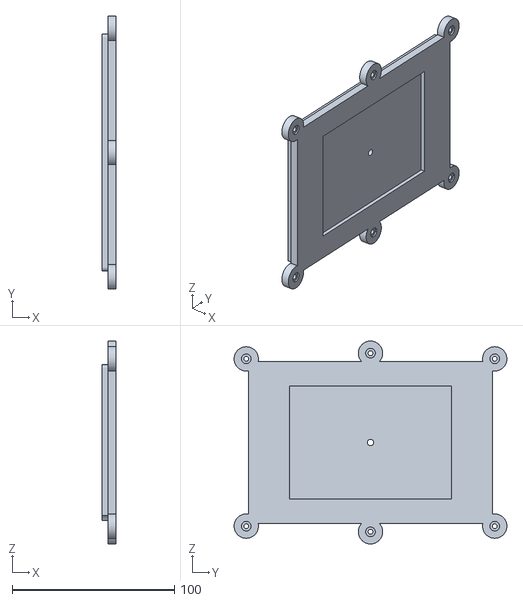
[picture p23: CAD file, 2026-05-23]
hardware/cases/rectangular-v10/top-lid.stl
8.75 x 168.0 x 125.0

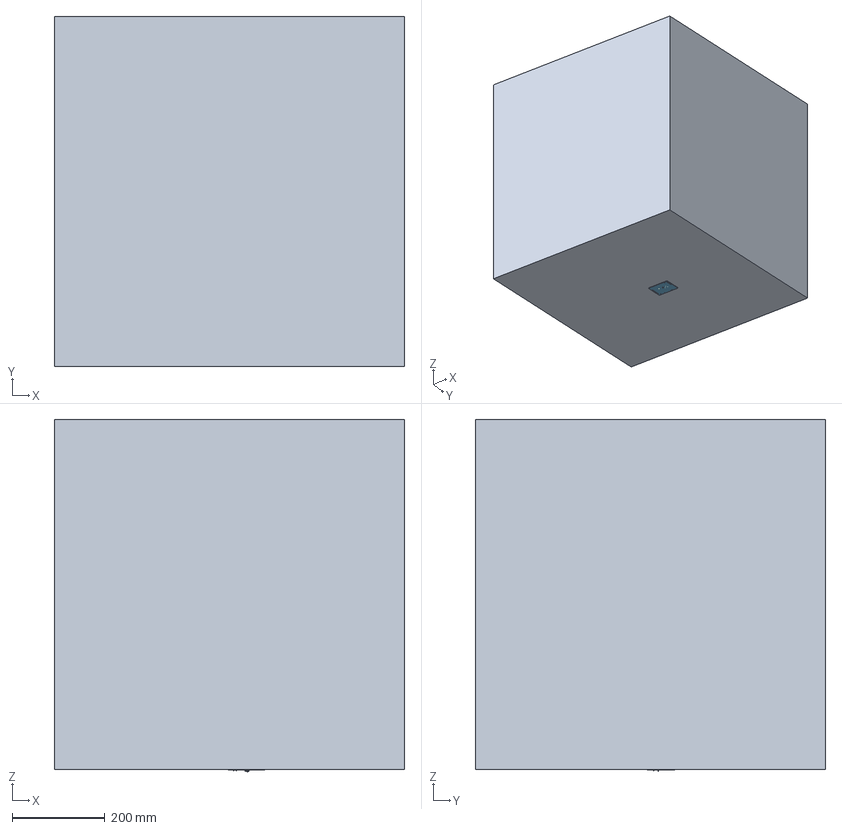
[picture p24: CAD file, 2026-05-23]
hardware/pcb/rx-pcb-3d.step
756.0 x 756.0 x 761.0 mm
Board~S2AT
TopCopper~S2AT
BottomCopper~S2AT
TopFpcStiffener~S2AT
BottomFpcStiffener~S2AT
CAP-TH_BD10.0-P5.00-D1.0-FD~CAP-TH_D10.0-H16.0-P5.00~S2AT
OLED-TH12864~OLED-TH12864~S2AT
3PIN_2.54_MM_JST_XHP_JST_CONNECTOR-TRUNG~jst - xh - thru (v) - 3pin - 2.54mm~S2AT

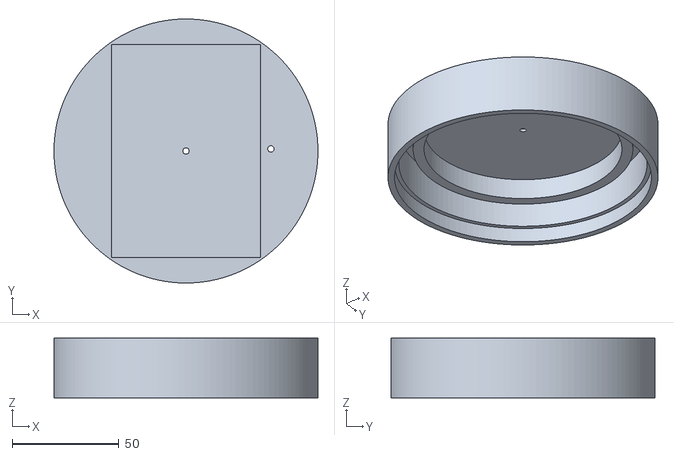
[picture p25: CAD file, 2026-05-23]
hardware/cases/circular-v1/top-with-solar.stl
123.5 x 123.5 x 28.0

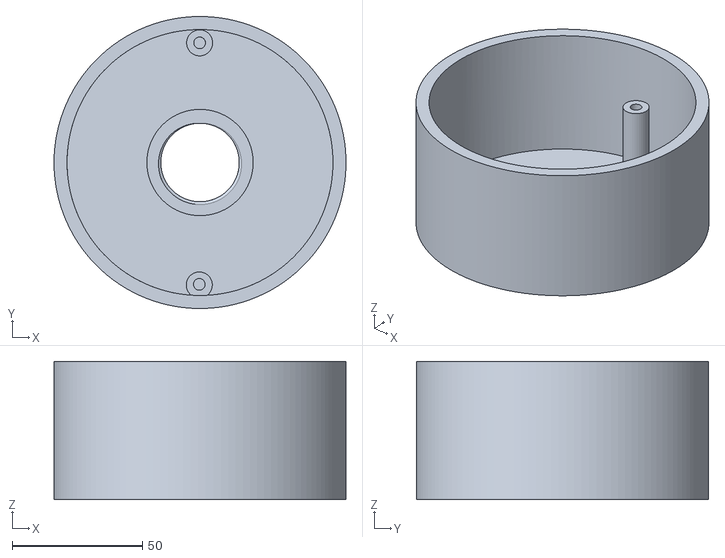
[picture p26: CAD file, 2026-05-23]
hardware/cases/circular-v1/base-holder.stl
112.0 x 112.0 x 53.0

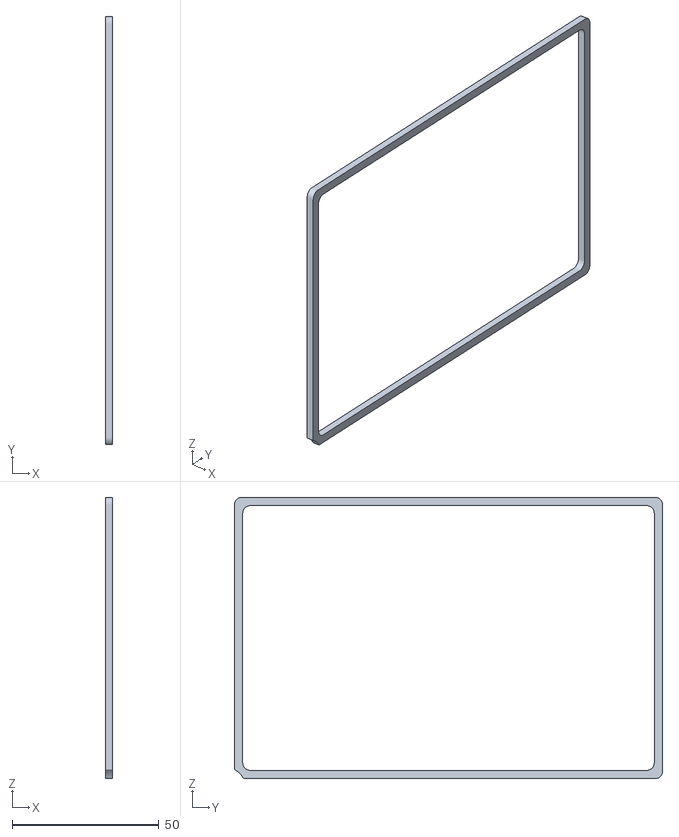
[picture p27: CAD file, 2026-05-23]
hardware/cases/rectangular-v10/tpu-gasket.stl
2.50 x 145.8 x 95.8

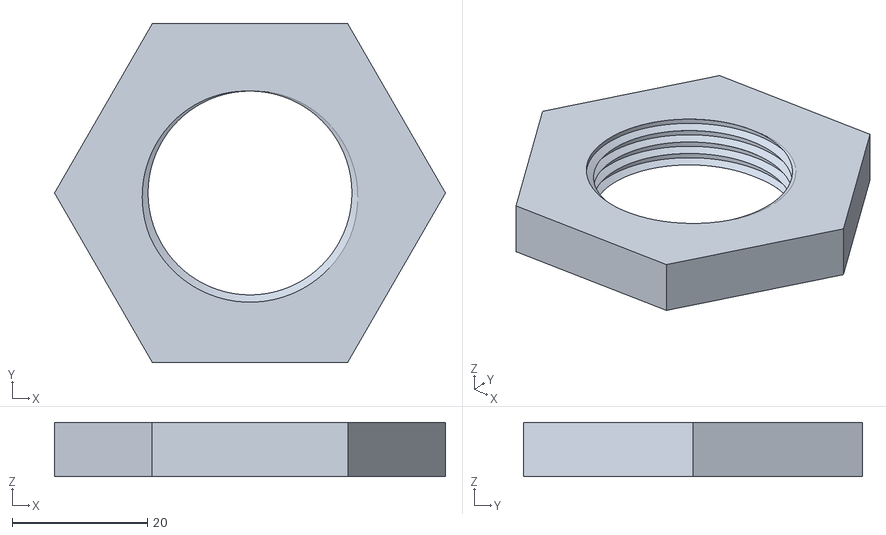
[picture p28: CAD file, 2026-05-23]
hardware/cases/circular-v1/nut.stl
57.7 x 50.0 x 8.03

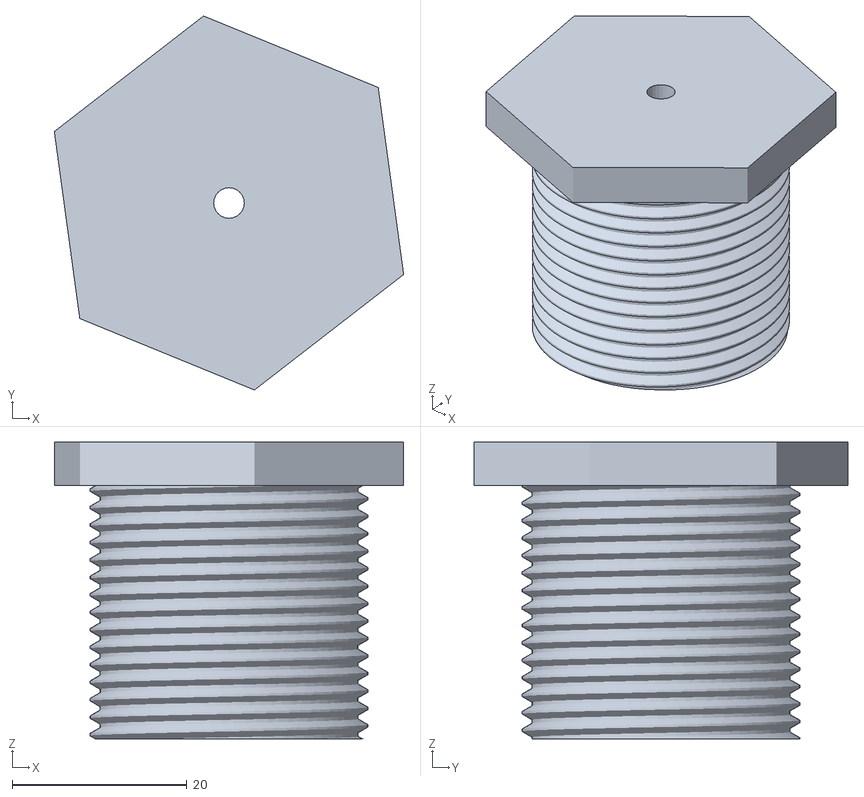
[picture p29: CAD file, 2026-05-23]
hardware/cases/circular-v1/sensor-screw.stl
40.0 x 42.8 x 34.0

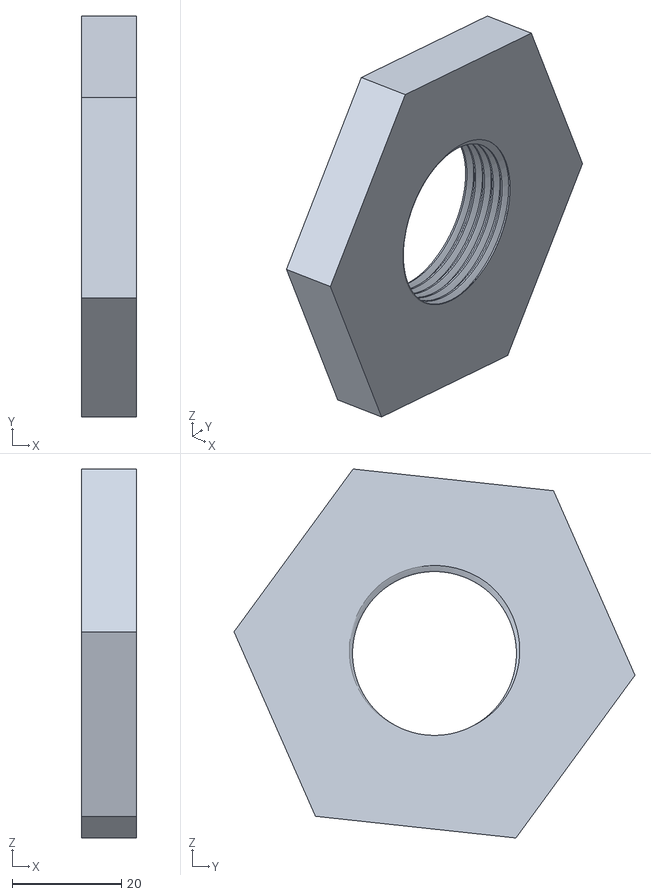
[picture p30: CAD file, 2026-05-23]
hardware/cases/rectangular-v10/bolt-screw.stl
10.0 x 73.5 x 67.6

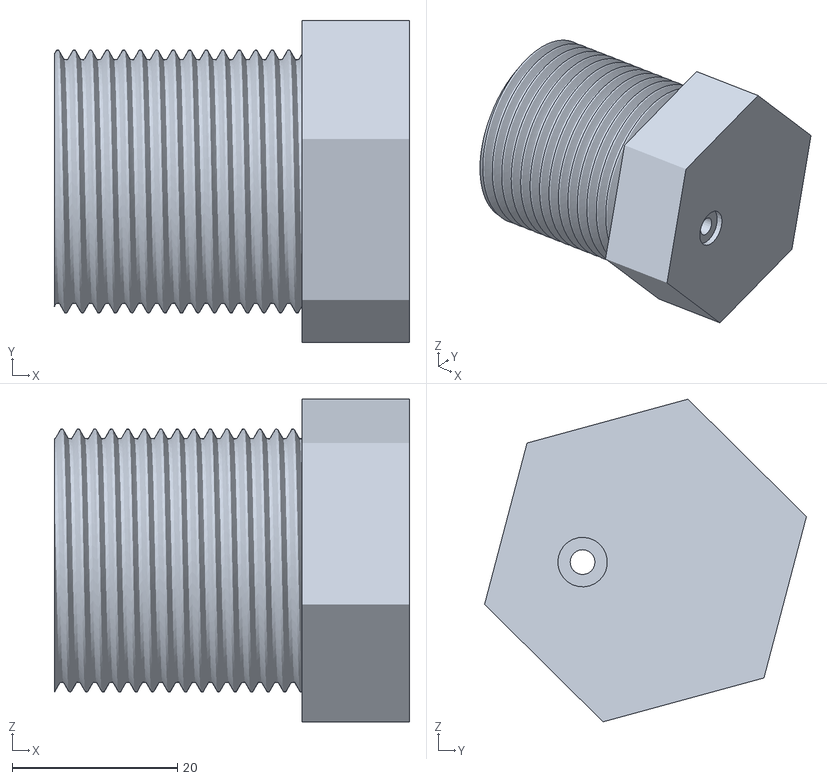
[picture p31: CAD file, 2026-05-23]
hardware/cases/rectangular-v10/sensor-screw.stl
43.0 x 39.0 x 39.1

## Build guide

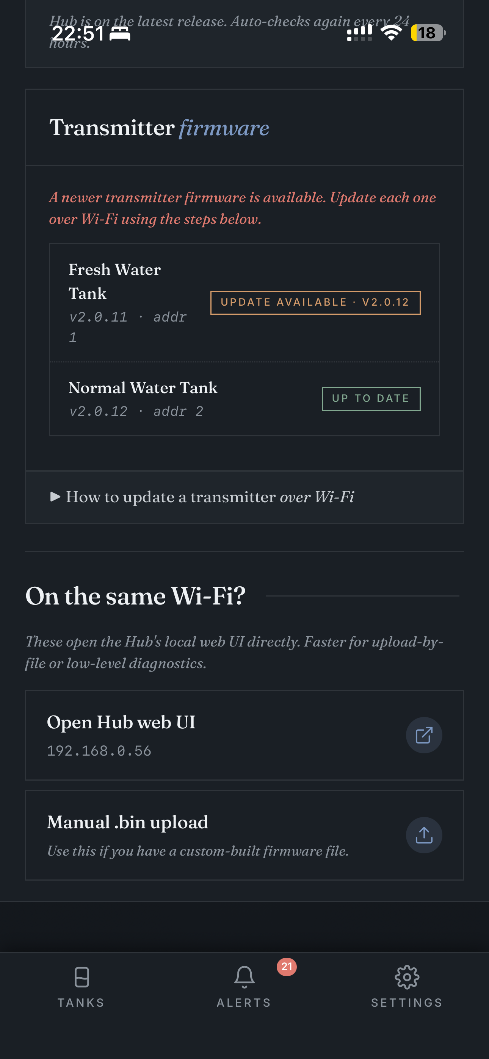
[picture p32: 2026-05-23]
docs/screenshots/pwa/firmware-update-manual-upload.png

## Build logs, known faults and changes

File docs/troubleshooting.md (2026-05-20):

# Troubleshooting

## Receiver

### WiFi scan button does nothing
The receiver uses APSTA mode for scanning. If scan still fails, try rebooting the receiver.

### Captive portal doesn't appear
After connecting to the "TankSync" WiFi, try opening `http://192.168.4.1` manually. iOS/Android auto-redirect is supported but may not work on all devices.

### OLED shows "NO DATA"
No transmitter is paired yet. Go to the receiver's web UI and press "Start Pairing", then power on the transmitter.

### MQTT shows "disconnected"
- Check WiFi is connected (receiver web UI -> System tab)
- Verify MQTT broker host and port are correct
- If using TLS (port 8883), ensure `use_tls` is enabled
- Check MQTT username and password

### OTA update fails
- Ensure the `.bin` file matches your board (ESP32 DevKit vs ESP32-C3)
- File must be under 1.5MB (OTA partition limit)
- Try uploading via the web UI at `http://<receiver-ip>/api/ota/upload`

## Transmitter

### Transmitter won't pair
- Ensure transmitter and receiver are using the same LoRa frequency
- Transmitter must be powered on within 60 seconds of pressing "Start Pairing" on the receiver
- Try power cycling the transmitter
- On rx-v2.7.10+, both sides rendezvous on the well-known pair NETID (6) automatically during the pair window — you do NOT need to set NETID manually. If a TX from an even older firmware still won't pair, flash it with `tx-v2.0.11` or later.

### "Tank disappeared" / one tank stopped reporting after pairing a second one
- This was a known issue on rx-v2.7.9 and earlier — pairing a second TX rotated the receiver's NETID, silently orphaning the first one. **Fixed in rx-v2.7.10:** the NETID is now generated once on the first-ever pair and kept stable across all subsequent pairs.
- If you're still seeing this on 2.7.10+, the most likely cause is a TX still on old firmware (pre-2.0.6). Either flash the TX, or factory-reset the hub and re-pair both TXs.

### Re-paired a tank and it came back as "Tank N" instead of my custom name
- The name + capacity + alerts are preserved by a *tombstone* archive — but only for TXs that sent their MAC in PAIR_REQ (tx-v2.0.11 onwards).
- A TX paired with older firmware doesn't have a MAC stored in the hub registry, so its delete is a hard-delete and re-pair creates a fresh entry.
- One-time migration: flash the TX with `tx-v2.0.11` or later, then delete + re-pair once. From then on, the MAC is recorded and future deletes preserve the name.

### Tank still shows in PWA after I deleted it
- Was a known issue before rx-v2.7.11 — the cloud DB delete didn't propagate to the receiver, so the hub re-synced the tank back into the cloud on its next refresh.
- **Fixed in rx-v2.7.11 + cloud (deployed 2026-05-21):** the cloud `DELETE` now publishes an MQTT `remove_tx` command to the receiver and waits for ack before removing the DB row. If the receiver is offline, the delete is refused with a clear error so you can retry once it reconnects.
- If you still see the tank after the cloud says "removed", hard-refresh the PWA (close + reopen) to clear the local cache.

### Pair button on PWA seems to do nothing
- The receiver listens for 60 seconds. Make sure to hold the transmitter's BOOT button for 2 seconds and release within that window.
- On rx-v2.7.11+ the PWA shows a "Linking to your account..." spinner while the cloud saves the new tank, followed by "🎉 Paired!" with the tank's name. If you see "no transmitter responded" instead, the receiver heard nothing — check that the receiver and transmitter are within range and that the receiver isn't already paired with the same physical sensor.

### I have multiple hubs at the same location — will they interfere?
No. Three layers of isolation protect each hub:
1. **NETID** — each hub generates a random LoRa Network ID (1-200) on its first ever pair, then keeps it forever. The RYLR998 radios filter by NETID at the *radio* level, so Hub A's TXs literally never reach Hub B's MCU.
2. **Pair-mode is single-hub at a time** — when you tap "Pair a Tank" in the PWA with multiple hubs, the wizard asks which hub to pair to. Only that one hub listens for the new transmitter.
3. **Cloud topic scoping** — each hub has its own MAC-derived device ID, so MQTT topics and cloud-DB tank lists are partitioned per hub. Tanks under Hub A never appear under Hub B.

You can see each hub's NETID + frequency in PWA Settings → expand the hub row. If two hubs ever ended up on the same NETID (~0.5% chance per pair of fresh hubs), factory-reset one — its first pair will pick a different value.

### I need to start over completely (resale, lab swap, troubleshooting)
- Web UI → System tab → **Factory Reset** button. Type `ERASE` to confirm.
- This wipes Wi-Fi credentials, MQTT credentials, all paired tanks, the tombstone archive, history, and LoRa NETID.
- The hub reboots into setup AP mode (`TankSync` open network at 192.168.4.1).

### Battery shows 0%
- Check the battery voltage divider wiring
- The ADC calibration assumes a 100K/100K divider on GPIO 0
- If using a different divider ratio, adjust in `config.h`

### Distance reading is stuck or wrong
- SR04T sensor needs a clear line of sight to the water surface
- Minimum distance: 25cm, maximum: 400cm
- Check sensor wiring (TRIG and ECHO pins)

## TankSync Cloud

### Can't sign up (captcha fails)
- Disable VPN or ad blockers temporarily
- Try a different browser
- Clear cookies and try again

### Email verification code not received
- Check spam/junk folder
- Emails come from `onboarding@resend.dev` (or `noreply@smartghar.org` if domain verified)
- Click "Resend code" (rate limited to 3 per 5 minutes)

### QR code scan doesn't work
- Ensure your phone and the TankSync Cloud server are on the same network as the receiver
- The QR code contains the receiver's local IP — it must be reachable from the server
- If on a different network, manually enter MQTT details in the receiver's web UI

### Dashboard shows stale data
- Check receiver's MQTT connection status in its web UI
- If using TankSync Cloud, verify the receiver is connected to `mqtt.smartghar.org:8883`
- The transmitter sends data every sleep interval (default 5 minutes)

### Push notifications not working
- Install the app as a PWA (Add to Home Screen)
- Enable notifications when prompted
- VAPID keys must be configured in the server's `.env` file

## Hardware

### LoRa range is poor
- Ensure antennas are attached to both RYLR998 modules
- Higher mounting = better range
- Avoid metal obstructions between transmitter and receiver
- Try increasing spreading factor in LoRa settings (higher SF = longer range, slower speed)

### Solar charging not working
- TP4056 module needs direct sunlight on the panel
- Check that the solar panel output is 5-6V
- The charge LED on TP4056 should be red when charging

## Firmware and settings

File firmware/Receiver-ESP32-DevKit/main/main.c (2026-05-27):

/**
 * TankSync Receiver v2 — app_main
 *
 * Boot sequence:
 *   1. NVS init
 *   2. Registry (SPIFFS + transmitter data model)
 *   3. WiFi (STA or AP fallback)
 *   4. Web server (always on — works in AP mode too)
 *   5. MQTT (only when WiFi connected)
 *   6. LoRa RX task (always listening)
 *   7. Display task (SH1106 OLED)
 *   8. LED task (WS2812B)
 *   9. OTA manager (24h auto-check)
 *
 * Inter-task communication: single EventGroupHandle_t (s_events)
 * Data store: transmitter_registry (mutex-protected, SPIFFS persistence)
 */

#include "config.h"
#include "transmitter_registry.h"
#include "wifi_manager.h"
#include "mqtt_manager.h"
#include "ota_manager.h"
#include "geo_time.h"
#include "web_server.h"
#include "lora_rylr998.h"
#include "display_sh1106.h"
#include "led_ws2812.h"
#include "buzzer.h"
#include "log_buffer.h"

#include "esp_log.h"
#include "esp_timer.h"
#include "esp_system.h"
#include "nvs_flash.h"
#include "nvs.h"
#include "freertos/FreeRTOS.h"
#include "freertos/task.h"
#include "freertos/event_groups.h"
#include <string.h>
#include <stdio.h>
#include <time.h>

static const char *TAG = "main";

// Build provenance fingerprint — preserved across releases for audit.
// Referenced in app_main below so the linker keeps it in .rodata.
static const uint32_t TS_BUILD_FP = 0xA3F1D582u;

// ── System-wide event group (shared with all components) ──────────────────────
static EventGroupHandle_t s_events;

// ── LoRa OTA synchronisation primitives ──────────────────────────────────────
// Written by on_lora_raw_rx (lora_rx_task context), read by lora_ota_task.
static volatile uint32_t s_ota_ack_offset = 0;  // last confirmed TX offset
static SemaphoreHandle_t s_ota_ack_sem   = NULL; // given when OTA_ACK received
static SemaphoreHandle_t s_ota_ready_sem = NULL; // given when OTA_READY received
static volatile int64_t  s_ota_task_start_us = 0;    // timestamp guard — auto-expires
#define OTA_TASK_MAX_US  (120LL * 1000000LL)         // 2-minute max lifetime

// Forward declarations
static void lora_ota_task(void *arg);
static void history_timer_cb(void *arg);

// ── Raw LoRa RX callback — handles OTA_ACK / OTA_READY / SET_ACK ─────────────
static void on_lora_raw_rx(uint16_t src_addr, const char *payload,
                            int rssi, int snr) {
    (void)rssi; (void)snr;
    if (strncmp(payload, "OTA_ACK:", 8) == 0) {
        s_ota_ack_offset = (uint32_t)strtoul(payload + 8, NULL, 10);
        xSemaphoreGive(s_ota_ack_sem);
        ESP_LOGI(TAG, "OTA_ACK from %d: offset=%" PRIu32, src_addr, s_ota_ack_offset);
    } else if (strcmp(payload, "OTA_READY") == 0) {
        xSemaphoreGive(s_ota_ready_sem);
        ESP_LOGI(TAG, "OTA_READY from %d", src_addr);
    } else if (strcmp(payload, "OTA_DONE") == 0) {
        ESP_LOGI(TAG, "OTA_DONE from %d — transmitter rebooting", src_addr);
        registry_set_ota_progress(src_addr, 0, false); // mark complete
    } else if (strncmp(payload, "OTA_ERR:", 8) == 0) {
        ESP_LOGE(TAG, "OTA_ERR from %d: %s", src_addr, payload + 8);
        // Give ACK sem so lora_ota_task unblocks and sees offset mismatch
        xSemaphoreGive(s_ota_ack_sem);
    } else if (strcmp(payload, "SET_ACK") == 0) {
        ESP_LOGI(TAG, "Config acknowledged by %d — clearing pending flag", src_addr);
        registry_clear_pending_config(src_addr);
    } else {
        ESP_LOGD(TAG, "Raw from %d: %s", src_addr, payload);
    }
}


// ─── Per-TX buzzer alert state tracker ───────────────────────────────────────
// Tracks the last tank-tier alert we played for each TX so we can:
//   (a) fire transition alerts only on tier change, not on every packet
//   (b) re-trigger sustained alerts at the design cadence (60s critical, 30s
//       overflow, 5min low warning, 10min sensor offline) via history_timer_cb
// State is keyed by registry index. registry indices are stable for a TX's
// lifetime, so we don't need to hash by address.
typedef enum {
    ALERT_TIER_NONE      = 0,
    ALERT_TIER_LOW       = 1,   // <20% but ≥5%
    ALERT_TIER_CRITICAL  = 2,   // <5%
    ALERT_TIER_OVERFLOW  = 3,   // >95%
} buzz_tier_t;

#define BUZZ_MAX_TANKS 16
// TX battery alert fires once when crossing below this threshold. 20% leaves
// the user a few days to swap/charge before the TX dies. We do NOT recur — a
// running pump or empty tank is fix-it-now; a low TX battery is fix-it-soon.
#define BUZZ_TX_BAT_LOW_PCT 20
static struct {
    buzz_tier_t tier;
    int64_t     last_repeat_us;   // 0 = never repeated since entering tier
    bool        sensor_alert_active;
    int64_t     sensor_alert_last_us;
    bool        bat_low_active;   // armed once seen above threshold; fires once on cross-below
    bool        bat_seen_high;    // suppresses first-boot beep before any high reading exists
} s_buzz_per_tank[BUZZ_MAX_TANKS] = {0};

static buzz_tier_t classify_tier(int water_pct) {
    if (water_pct >  95) return ALERT_TIER_OVERFLOW;
    if (water_pct <   5) return ALERT_TIER_CRITICAL;
    if (water_pct <  20) return ALERT_TIER_LOW;
    return ALERT_TIER_NONE;
}

// Called from on_lora_rx after registry update — fires one-shot transition alerts.
static void buzz_check_transition(int idx, int water_pct, bool sensor_error, int battery_pct) {
    if (idx < 0 || idx >= BUZZ_MAX_TANKS) return;
    buzz_tier_t cur = classify_tier(water_pct);
    if (cur != s_buzz_per_tank[idx].tier) {
        s_buzz_per_tank[idx].tier = cur;
        s_buzz_per_tank[idx].last_repeat_us = esp_timer_get_time();
        switch (cur) {
            case ALERT_TIER_CRITICAL: buzzer_play(BUZZ_CRITICAL_LOW); break;
            case ALERT_TIER_OVERFLOW: buzzer_play(BUZZ_OVERFLOW);     break;
            case ALERT_TIER_LOW:      buzzer_play(BUZZ_LOW_WARNING);  break;
            default: /* recovered to NONE — no celebratory beep */    break;
        }
    }
    // Edge-triggered sensor-error alert.
    if (sensor_error && !s_buzz_per_tank[idx].sensor_alert_active) {
        s_buzz_per_tank[idx].sensor_alert_active  = true;
        s_buzz_per_tank[idx].sensor_alert_last_us = esp_timer_get_time();
        buzzer_play(BUZZ_SENSOR_OFFLINE);
    } else if (!sensor_error) {
        s_buzz_per_tank[idx].sensor_alert_active = false;
    }
    // Edge-triggered TX low-battery alert. Requires having seen the battery
    // above threshold at least once first — otherwise a brand-new TX paired
    // at <20% would beep on the very first packet, which is noise.
    if (battery_pct >= BUZZ_TX_BAT_LOW_PCT) {
        s_buzz_per_tank[idx].bat_seen_high = true;
        s_buzz_per_tank[idx].bat_low_active = false;
    } else if (battery_pct > 0 && battery_pct < BUZZ_TX_BAT_LOW_PCT
               && s_buzz_per_tank[idx].bat_seen_high
               && !s_buzz_per_tank[idx].bat_low_active) {
        s_buzz_per_tank[idx].bat_low_active = true;
        buzzer_play(BUZZ_TX_LOW_BATTERY);
    }
}

// Called from history_timer_cb (every 60s) — re-fires sustained alerts.
static void buzz_check_repeats(void) {
    // Only fix-it-now conditions get recurring repeats. Overflow (>95%) and
    // low warning (<20%) are edge-triggered only via buzz_check_transition —
    // a full tank sitting at 100% after refill is the desired state, not a
    // crisis to nag the user about every 30s.
    int64_t now = esp_timer_get_time();
    int tx_count = registry_count();
    if (tx_count > BUZZ_MAX_TANKS) tx_count = BUZZ_MAX_TANKS;
    for (int i = 0; i < tx_count; i++) {
        tx_data_t d;
        if (!registry_get_data(i, &d)) continue;
        // Bug fix (rx-v2.8.4): only alert on tanks we have CURRENT data for.
        // A never-reported tank has water_pct=0 in memory from registry init,
        // which classify_tier() reads as CRITICAL — would fire false-positive
        // Critical-low beeps every 60s for any unpaired-but-registered slot.
        // Stale/lost tanks also shouldn't keep nagging — the sensor-offline
        // alert covers that case at a different cadence.
        if (!d.data_valid || d.state != TX_STATE_CONNECTED) continue;
        buzz_tier_t cur = classify_tier(d.water_pct);
        int64_t since = now - s_buzz_per_tank[i].last_repeat_us;
        if (cur == ALERT_TIER_CRITICAL && since >= 60LL * 1000000LL) {
            buzzer_play(BUZZ_CRITICAL_LOW);
            s_buzz_per_tank[i].last_repeat_us = now;
        }
        // Overflow gets a gentle 1-hour re-nag — no on-screen escalation
        // tier exists above 100% (vs critical-low for low-water), so without
        // a slow re-nag a missed first alert means an actively-overflowing
        // pump wastes water + electricity unnoticed for hours.
        if (cur == ALERT_TIER_OVERFLOW && since >= 3600LL * 1000000LL) {
            buzzer_play(BUZZ_OVERFLOW);
            s_buzz_per_tank[i].last_repeat_us = now;
        }
        if (s_buzz_per_tank[i].sensor_alert_active) {
            int64_t since_s = now - s_buzz_per_tank[i].sensor_alert_last_us;
            if (since_s >= 600LL * 1000000LL) {
                buzzer_play(BUZZ_SENSOR_OFFLINE);
                s_buzz_per_tank[i].sensor_alert_last_us = now;
            }
        }
    }
}

// ─────────────────────────────────────────────────────────────────────────────
// LoRa RX callback — called from lora_rx_task when packet arrives
// ─────────────────────────────────────────────────────────────────────────────
static void on_lora_rx(const lora_rx_packet_t *pkt) {
    if (!pkt->data_valid) return;

    bool updated = registry_update_data(
        pkt->src_addr, pkt->raw_dist_cm,
        pkt->battery_pct, pkt->battery_voltage,
        pkt->msg_id, pkt->rssi, pkt->snr,
        pkt->fw_version,
        pkt->power_mode, pkt->current_ma, pkt->power_mw,
        pkt->sensor_status,
        pkt->sensor_kind);

    if (updated) {
        xEventGroupSetBits(s_events, EVT_NEW_LORA_DATA);
        // Publish to MQTT immediately
        int idx = registry_find(pkt->src_addr);
        if (idx >= 0) mqtt_publish_tank(idx);

        // Buzzer alerts — transition-only (re-trigger cadence is handled in
        // history_timer_cb at 60s tick). Fetches current data to read the
        // just-applied water_pct + sensor_error.
        if (idx >= 0) {
            tx_data_t d;
            if (registry_get_data(idx, &d)) {
                buzz_check_transition(idx, d.water_pct, d.sensor_error, d.battery_pct);
            }
        }

        // CHECK FOR PENDING CONFIG DOWNLINK
        uint32_t sleep_s; uint8_t samples; uint8_t pwr;
        char sensor_kind[12] = {0};
        if (registry_get_pending_config(pkt->src_addr, &sleep_s, &samples, &pwr,
                                        sensor_kind, sizeof(sensor_kind))) {
            // Build SET frame incrementally. Sleep + samples are always present;
            // PWR and SENSOR are appended only when non-default so legacy TX
            // firmwares (pre-2.0.15) safely ignore the trailing tokens.
            char cmd[96];
            int  n = snprintf(cmd, sizeof(cmd), "SET:SLEEP=%u:SAMP=%u",
                              (unsigned)sleep_s, samples);
            if (pwr > 0 && n < (int)sizeof(cmd)) {
                n += snprintf(cmd + n, sizeof(cmd) - n, ":PWR=%u", pwr);
            }
            if (sensor_kind[0] && n < (int)sizeof(cmd)) {
                n += snprintf(cmd + n, sizeof(cmd) - n, ":SENSOR=%s", sensor_kind);
            }
            ESP_LOGI(TAG, "Sending downlink config to %d: %s", pkt->src_addr, cmd);
            vTaskDelay(pdMS_TO_TICKS(500)); // Brief delay after ACK
            lora_send_async(pkt->src_addr, cmd);
        }

        // CHECK FOR PENDING LORA OTA
        bool ota_p = false; uint32_t ota_o = 0;
        if (registry_get_ota_status(pkt->src_addr, &ota_p, &ota_o) && ota_p && ota_o == 0) {
            bool ota_busy = s_ota_task_start_us > 0 &&
                (esp_timer_get_time() - s_ota_task_start_us) < OTA_TASK_MAX_US;
            if (ota_busy) {
                ESP_LOGW(TAG, "OTA task already running — skipping for %d", pkt->src_addr);
            } else {
                // Drain stale semaphores before spawning OTA task
                xSemaphoreTake(s_ota_ready_sem, 0);
                xSemaphoreTake(s_ota_ack_sem,   0);
                // Spawn OTA task — it handles OTA_START, param switch, and chunks.
                // This avoids blocking lora_rx_task for 5+ seconds during OTA_START
                // sends, which would cause UART buffer overflow and lost OTA_READY.
                ESP_LOGI(TAG, "Triggering LoRa OTA task for %d", pkt->src_addr);
                xTaskCreate(lora_ota_task, "lo_ota", 4096, (void*)(uintptr_t)pkt->src_addr, 5, NULL);
            }
        }
    }
}

// ─────────────────────────────────────────────────────────────────────────────
// Display helpers
// ─────────────────────────────────────────────────────────────────────────────
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
void app_main(void) {
    // Install the log ring buffer FIRST so even the boot banner is captured
    // and served via /api/logs to the dashboard / curl users. 4 KB in RAM,
    // forwards every line through to the original sink (UART console + USB
    // serial monitor) so existing workflows are untouched.
    log_buffer_init();

    ESP_LOGI(TAG, "TankSync Receiver v%s booting (build %08X)", FIRMWARE_VERSION, (unsigned)TS_BUILD_FP);

    // ── 1. NVS ──
    esp_err_t err = nvs_flash_init();
    if (err == ESP_ERR_NVS_NO_FREE_PAGES || err == ESP_ERR_NVS_NEW_VERSION_FOUND) {
        ESP_LOGW(TAG, "NVS full/version mismatch — erasing");
        ESP_ERROR_CHECK(nvs_flash_erase());
        err = nvs_flash_init();
    }
    ESP_ERROR_CHECK(err);

    // ── 2. Event group ──
    s_events = xEventGroupCreate();
    ESP_ERROR_CHECK(s_events ? ESP_OK : ESP_ERR_NO_MEM);

    // ── 3. Transmitter registry (SPIFFS) ──
    ESP_ERROR_CHECK(registry_init());

    // ── 3b. Buzzer driver — needs NVS only (no network deps). Boot tone fires
    // at end of app_main, after all subsystems initialize, so the user hears
    // "I'm fully alive" rather than "init started".
    ESP_ERROR_CHECK(buzzer_init(PIN_BUZZER));

    // ── 4. WiFi ──
    ESP_ERROR_CHECK(wifi_manager_init(s_events));
    wifi_manager_connect();  // STA if creds saved, AP fallback

    // ── 4b. SNTP wall-clock + IP-geolocation country code ──
    // Spawns a background task that waits for WiFi and then sets up SNTP
    // and one-shot ip-api.com country detect. Used by web UI for LoRa
    // compliance hints + future hourly-history-bucket alignment.
    ESP_ERROR_CHECK(geo_time_init());

    // ── 5. MQTT init (doesn't connect yet) ──
    ESP_ERROR_CHECK(mqtt_manager_init());

    // ── 6. Web server (works in both STA and AP mode) ──
    ESP_ERROR_CHECK(web_server_start());

    // ── 7. LoRa ──
    // Create OTA sync primitives before lora_init so callbacks are ready
    s_ota_ack_sem   = xSemaphoreCreateBinary();
    s_ota_ready_sem = xSemaphoreCreateBinary();
    ESP_ERROR_CHECK((s_ota_ack_sem && s_ota_ready_sem) ? ESP_OK : ESP_ERR_NO_MEM);

    esp_err_t lora_err = lora_init(LORA_UART_NUM, PIN_LORA_TX, PIN_LORA_RX, LORA_BAUD);
    if (lora_err != ESP_OK) {
        ESP_LOGW(TAG, "LoRa init failed — continuing without LoRa (web UI still available)");
    }
    lora_set_rx_callback(on_lora_rx);
    lora_set_raw_rx_callback(on_lora_raw_rx);
    // LoRa RX task is spawned inside lora_init

    // ── 8. OTA manager (marks current firmware valid, starts 24h check loop) ──
    ESP_ERROR_CHECK(ota_manager_init());

    // ── 9. Application tasks ──
    xTaskCreate(display_task,   "display",    STACK_DISPLAY, NULL, TASK_PRIO_DISPLAY, NULL);
    xTaskCreate(led_task,       "led",        STACK_LED,     NULL, TASK_PRIO_LED,     NULL);
    xTaskCreate(wifi_watch_task,"wifi_watch", 3072,          NULL, TASK_PRIO_WIFI,    NULL);

    // ── 10. Half-hourly history tick (Phase 2) ──
    // Fires every 60s; the tick fn no-ops within the same 30-min bucket. Once
    // SNTP syncs, slot capture begins. Persists to /spiffs/tx_hist.bin every
    // hour (skip-if-clean) so reboots don't wipe the rolling 24-h window.
    {
        const esp_timer_create_args_t hist_args = {
            .callback = &history_timer_cb,
            .name     = "hist_tick",
        };
        esp_timer_handle_t hist_timer = NULL;
        if (esp_timer_create(&hist_args, &hist_timer) == ESP_OK) {
            esp_timer_start_periodic(hist_timer, 60ULL * 1000000ULL);
            ESP_LOGI(TAG, "History tick started (60s period)");
        } else {
            ESP_LOGW(TAG, "Failed to create history timer — predictions will be live-only");
        }
    }

    ESP_LOGI(TAG, "All tasks started. Free heap: %lu bytes",
             (unsigned long)esp_get_free_heap_size());

    // Boot tone — bypasses master_enable + quiet hours by design.
    // Confirms "I'm on, I'm working" — useful for setup, post-outage, post-OTA.
    buzzer_play(BUZZ_BOOT_COMPLETE);

    // app_main can now exit (or loop here for monitoring)
    // Deleting ourselves frees the 8KB app_main stack
    vTaskDelete(NULL);
}

// ── LoRa OTA Task (Receiver) ─────────────────────────────────────────────────
//
// Protocol:
//   RX → TX  OTA_START:<total_bytes>     (transmitter wakes OTA handler)
//   TX → RX  OTA_READY                   (transmitter ready, s_ota_ready_sem given)
//   RX → TX  OTA_DATA:<offset>:<hexdata> (100-byte chunk = 200 hex chars, ≤219 bytes total)
//   TX → RX  OTA_ACK:<next_offset>       (per-chunk, s_ota_ack_sem given)
//   RX → TX  OTA_END                     (all chunks sent)
//   TX → RX  OTA_DONE                    (transmitter verified + rebooting)
//
// Timeouts: 8 s for OTA_READY, 8 s per chunk ACK.  3 retries per chunk.
// Chunk size: 100 bytes → 200 hex chars.  OTA_DATA:4294967295: = 19 chars.
//   Total = 219 bytes < 240-byte RYLR998 payload limit.
//
#define OTA_CHUNK_BYTES   100
#define OTA_READY_TIMEOUT pdMS_TO_TICKS(8000)
#define OTA_ACK_TIMEOUT   pdMS_TO_TICKS(2000)
#define OTA_MAX_RETRIES   10

static void lora_ota_task(void *arg) {
    s_ota_task_start_us = esp_timer_get_time();
    uint16_t addr = (uint16_t)(uintptr_t)arg;
    ESP_LOGI(TAG, "LoRa OTA start → addr %d", addr);

    // NOTE: semaphores are drained in on_lora_rx BEFORE this task is spawned.

    FILE *f = fopen("/spiffs/tx_fw.bin", "rb");
    if (!f) {
        ESP_LOGE(TAG, "No staged firmware at /spiffs/tx_fw.bin");
        registry_set_ota_progress(addr, 0, false);
        s_ota_task_start_us = 0;
        vTaskDelete(NULL);
        return;
    }

    fseek(f, 0, SEEK_END);
    uint32_t total_size = (uint32_t)ftell(f);
    rewind(f);
    ESP_LOGI(TAG, "Firmware size: %" PRIu32 " bytes", total_size);

    // ── Version check: skip OTA if TX already runs the staged firmware ──────
    char staged_ver[32] = {0};
    {
        uint8_t scan[256];
        size_t scan_off = 0;
        bool found = false;
        rewind(f);
        while (scan_off < 4096 && !found) {
            size_t n = fread(scan, 1, sizeof(scan), f);
            if (n < 4) break;
            for (size_t i = 0; i + 48 <= n; i += 4) {
                uint32_t w = (uint32_t)scan[i] | ((uint32_t)scan[i+1]<<8)
                           | ((uint32_t)scan[i+2]<<16) | ((uint32_t)scan[i+3]<<24);
                if (w == 0xABCD5432u) {
                    memcpy(staged_ver, &scan[i + 16], 31);
                    staged_ver[31] = '\0';
                    found = true;
                    break;
                }
            }
            if (!found && n == sizeof(scan)) {
                fseek(f, -(long)48, SEEK_CUR);
                scan_off += sizeof(scan) - 48;
            } else if (!found) break;
        }
        rewind(f);
    }
    if (staged_ver[0]) {
        int idx = registry_find(addr);
        if (idx >= 0) {
            tx_data_t data;
            if (registry_get_data(idx, &data) && data.fw_version[0] &&
                strcmp(data.fw_version, staged_ver) == 0) {
                ESP_LOGI(TAG, "TX %d already running v%s — skipping OTA", addr, staged_ver);
                fclose(f);
                registry_set_ota_progress(addr, 0, false);
                s_ota_task_start_us = 0;
                vTaskDelete(NULL);
                return;
            }
        }
        ESP_LOGI(TAG, "Staged firmware: v%s", staged_ver);
    }

    // ── Step 0: Send OTA_START to TX (at normal SF9/125kHz) ─────────────────
    char ota_start_cmd[48];
    snprintf(ota_start_cmd, sizeof(ota_start_cmd), "OTA_START:%" PRIu32, total_size);
    vTaskDelay(pdMS_TO_TICKS(500));
    ESP_LOGI(TAG, "Sending OTA_START to %d (%" PRIu32 " bytes) 3x", addr, total_size);
    for (int r = 0; r < 3; r++) {
        lora_send(addr, ota_start_cmd);
        vTaskDelay(pdMS_TO_TICKS(600));
    }

    // Switch to fast LoRa params for chunk streaming
    ESP_LOGI(TAG, "Switching to SF7/500kHz for OTA chunks");
    lora_send_cmd("AT+PARAMETER=7,9,1,12", 1500);

    // ── Step 1: Wait for TX to be ready ─────────────────────────────────────
    ESP_LOGI(TAG, "Waiting up to 8s for OTA_READY from %d...", addr);
    if (xSemaphoreTake(s_ota_ready_sem, pdMS_TO_TICKS(8000)) == pdTRUE) {
        ESP_LOGI(TAG, "OTA_READY received — proceeding");
    } else {
        ESP_LOGW(TAG, "OTA_READY not received — proceeding anyway (TX may be ready)");
    }
    vTaskDelay(pdMS_TO_TICKS(500));
    // ── Step 2: stream chunks ─────────────────────────────────────────────────
    char cmd[256];
    uint32_t offset = 0;
    uint8_t  chunk[OTA_CHUNK_BYTES];
    // hex buf: 2 chars/byte + null
    char hex[OTA_CHUNK_BYTES * 2 + 1];
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

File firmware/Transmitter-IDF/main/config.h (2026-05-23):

/**
 * TankSync Transmitter v2 - Central Configuration
 * ESP32-C3 SuperMini + RYLR998 + AJ-SR04M ultrasonic
 *
 * Pin assignments match existing v1.0 hardware — same physical boards.
 */

#pragma once

// ============================================================================
// FIRMWARE
// Version lives in ./VERSION (single source of truth). CMake reads it, sets
// PROJECT_VER (embedded into esp_app_desc.version at offset 0x30), and emits
// version_gen.h with FIRMWARE_VERSION as a #define. To bump version, edit
// ./VERSION only — nothing else.
// ============================================================================
#include "version_gen.h"
#define FIRMWARE_TYPE           "transmitter"

// ============================================================================
// PINS - ESP32-C3 SuperMini (unchanged from v1.0 hardware)
// ============================================================================
#define PIN_LORA_TX             21      // UART1 TX → RYLR998 RXD
#define PIN_LORA_RX             20      // UART1 RX ← RYLR998 TXD
#define PIN_LED                 8       // On-board LED for ESP32-C3 SuperMini
#define PIN_WS2812              7       // WS2812B data (single LED)
#define PIN_WS2812_COUNT        1       // Number of WS2812B LEDs (single, low power)
#define PIN_TRIG                4       // AJ-SR04M TRIG
#define PIN_ECHO                5       // AJ-SR04M ECHO
#define PIN_BUTTON              9       // Boot/config button (INPUT_PULLUP)

// ── +5V high-side switch (REV 2.2 hardware) ──────────────────────────────────
// PIN_5V_GATE drives Q3 (AO3400 N-FET) via R3 (1kΩ series), whose drain
// inverts the signal onto the gates of Q1 + Q2 (AO3401 P-FETs). Q1 switches
// +3.3V to the RYLR998 LoRa module; Q2 switches +5V to the AJ-SR04M and
// WS2812B. R1 (100kΩ) pulls Q3 gate to GND so the FETs stay OFF when the
// MCU is in reset/sleep — but only if the pin is actively driven LOW (a
// floating input + ESP32's internal weak pull-up + ESD-diode leakage gives
// ~0.77V on the gate, enough to drag the P-FET gate node low and keep the
// loads partially on, which is what was measured on the bench before this
// gate-drive was wired up in firmware).
//
// Wiring note (REV 2.2 as-built, 2026-05-17): GPIO10 was originally listed
// in the schematic plan to gate the MT3608 boost converter's EN pin — that
// route never made it to the PCB. GPIO10 IS routed to R3 → Q3 gate, which
// is its actually-used purpose on this board rev.
//
// Logic:  HIGH = wake-time, 5V loads enabled.  LOW = sleep, 5V loads off.
#define PIN_5V_GATE             10
#define PWR_SETTLE_MS           50      // AJ-SR04M takes ~30ms after V+ rises

// ============================================================================
// SENSOR - AJ-SR04M ultrasonic
// ============================================================================
#define SENSOR_TRIG_US          20      // Trigger pulse width (µs).
                                        // JSN-SR04T V3.0 datasheet specifies
                                        // 20 µs minimum for reliable operation
                                        // (vs HC-SR04's 10 µs). Especially
                                        // important in JSN Mode 4 (low-power
                                        // between-pings) where the analog
                                        // front-end is more sensitive to
                                        // marginal TRIG pulse widths.
#define SENSOR_TIMEOUT_US       30000   // Echo timeout = 5m (30000µs)
#define SENSOR_MIN_CM           5       // Reject readings below this
#define SENSOR_MAX_CM           400     // Reject readings above this
#define SENSOR_SAMPLES          5       // Readings per wake cycle; median used
#define SENSOR_SAMPLE_DELAY_MS  50      // Delay between samples

// Speed of sound factor: distance = echo_us / 58 (for cm)
#define SENSOR_US_TO_CM         58

// ============================================================================
// LORA - RYLR998
// ============================================================================
#define LORA_UART_NUM           UART_NUM_1
#define LORA_BAUD               115200
#define LORA_DEFAULT_FREQ       865000000   // 865 MHz
#define LORA_DEFAULT_NETID      6
#define LORA_DEFAULT_ADDR       1           // Transmitter address (unique per unit)
#define LORA_RECEIVER_ADDR      2           // Receiver's address
#define LORA_CMD_TIMEOUT_MS     1500
#define LORA_ACK_TIMEOUT_MS     3000        // Wait up to 3s for ACK
#define LORA_MAX_RETRIES        3           // Retry count if no ACK
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

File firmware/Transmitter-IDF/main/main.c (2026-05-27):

/**
 * TankSync Transmitter v2 — app_main
 *
 * Operation cycle (runs on every wake from deep sleep):
 *   1. Init peripherals (NVS, UART, ADC, GPIO)
 *   2. Read ultrasonic sensor (IQR filtered median)
 *   3. Read battery (ADC averaged)
 *   4. Initialize LoRa module, send packet with retries
 *   5. Listen for downlink (config/OTA) if ACK received
 *   6. Enter deep sleep
 *
 * On timer wake: skips boot window entirely for battery savings.
 * On power-on/reset: 10s boot window for pairing/diagnostics.
 */

#include "config.h"
#include "sensor_sr04.h"
#include "sensor_iface.h"
#include "battery_monitor.h"
#include "lora_tx.h"
#include "wifi_ota.h"
#include "led_ws2812.h"
#include "log_buffer.h"

#include "esp_log.h"
#include "esp_timer.h"
#include "esp_system.h"
#include "esp_random.h"
#include "esp_sleep.h"
#include "esp_ota_ops.h"
#include "nvs_flash.h"
#include "driver/gpio.h"
#include "freertos/FreeRTOS.h"
#include "freertos/task.h"
#include <stdio.h>
#include <string.h>

static const char *TAG = "main";

// Build provenance fingerprint — preserved across releases for audit.
static const uint32_t TS_BUILD_FP = 0xA3F1D582u;

// ── Diagnostic mode switch ───────────────────────────────────────────────────
// Set to 1, rebuild, and flash to turn this TX into a continuous-mode sensor
// tester. No deep sleep, no LoRa, no power management — just bang the sensor
// every second and print everything we know to serial. Used for diagnosing
// JSN-SR04M / AJ-SR04M variants that "click but don't report distance".
// Revert to 0 (or just rebuild without SENSOR_DIAG_MODE) for production.
#ifndef SENSOR_DIAG_MODE
#define SENSOR_DIAG_MODE  0
#endif

// ── Helpers ──────────────────────────────────────────────────────────────────
#define SEND_STR(s)  lora_tx_send_raw((s), strlen(s))
#define CLAMP(x, lo, hi)  ((x) < (lo) ? (lo) : ((x) > (hi) ? (hi) : (x)))

// Low-battery thresholds (INA219 bus-voltage, mV):
//   ≥ BAT_LOW_TX_MV  → normal TX
//   < BAT_LOW_TX_MV  → skip TX this cycle, extended sleep (preserves charge,
//                       prevents brown-out loop from a battery that still has
//                       static voltage but can't deliver the LoRa-burst current)
//   < BAT_CUTOFF_MV  → hibernate, protect LiPo from over-discharge
#define BAT_CUTOFF_MV       3100
#define BAT_LOW_TX_MV       3300
#define BAT_CUTOFF_SLEEP_S  3600    // 1 hour
#define BAT_LOW_TX_SLEEP_S  600     // 10 min — give battery time to recover

// OTA total timeout — prevent staying awake indefinitely on stalled OTA
#define OTA_TOTAL_TIMEOUT_MS  (5 * 60 * 1000)  // 5 minutes

// Brown-out / watchdog backoff — exponential, capped at 1h.
// streak=1 → 60s, =2 → 120s, =3 → 240s, =4 → 480s, =5 → 960s, =6 → 1920s,
// streak>=7 clamped to 3600s. Streak clears on next successful ACK.
#define BROWNOUT_BASE_SLEEP_S  60
#define BROWNOUT_MAX_SLEEP_S   3600

// ── RTC memory (survives deep sleep AND brown-out reset) ─────────────────────
// RTC_DATA_ATTR survives deep-sleep + most resets but NOT power-cycle. That's
// exactly what we want for the brown-out streak: counter persists across the
// brown-out → reboot cycle so we can back off, but a clean power-cycle starts
// fresh.
RTC_DATA_ATTR static uint32_t s_msg_id    = 0;
RTC_DATA_ATTR static uint32_t s_boot_count = 0;
RTC_DATA_ATTR static uint32_t s_ack_failures = 0;
RTC_DATA_ATTR static uint32_t s_brownout_streak = 0;

// ── Reset-reason helpers ────────────────────────────────────────────────────
// esp_sleep_get_wakeup_cause() only reflects DEEP-SLEEP wake causes. A brown-
// out reset returns ESP_SLEEP_WAKEUP_UNDEFINED, identical to a fresh power-on
// — so we MUST also call esp_reset_reason() to tell them apart. Without this
// distinction, the boot-window check at the bottom of app_main treats a
// brown-out the same as a user pressing reset (10s boot window, then sensor
// + LoRa TX → another brown-out → loop forever, burning battery instead of
// sleeping). This is the root cause of the "TX sometimes sleeps, sometimes
// loops forever" symptom — diagnosed 2026-05-25.
static const char *reset_reason_str(esp_reset_reason_t r) {
    switch (r) {
        case ESP_RST_POWERON:   return "POWERON";
        case ESP_RST_EXT:       return "EXT";
        case ESP_RST_SW:        return "SW";
        case ESP_RST_PANIC:     return "PANIC";
        case ESP_RST_INT_WDT:   return "INT_WDT";
        case ESP_RST_TASK_WDT:  return "TASK_WDT";
        case ESP_RST_WDT:       return "WDT";
        case ESP_RST_DEEPSLEEP: return "DEEPSLEEP";
        case ESP_RST_BROWNOUT:  return "BROWNOUT";
        case ESP_RST_SDIO:      return "SDIO";
        default:                return "UNKNOWN";
    }
}

// Forward decl — defined below.
static inline void ws2812_quiet_for_sleep(void);

// Go to deep sleep for N seconds without doing any other work. Used by the
// brown-out backoff and low-battery paths to skip the sensor + LoRa TX cycle
// entirely (which is what was causing the brown-out in the first place).
// Always quiets the WS2812 first so the LED doesn't stay latched on through
// sleep — also a visual confirmation that the chip is actually sleeping.
static void deep_sleep_for(uint32_t seconds, const char *reason) {
    ESP_LOGW("main", "Backoff sleep %lus (%s)", (unsigned long)seconds, reason);
    esp_sleep_enable_timer_wakeup((uint64_t)seconds * 1000000ULL);
    ws2812_quiet_for_sleep();
    esp_deep_sleep_start();
}
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

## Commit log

2026-01-03 Update LoRa Water Tank Monitor with modular receiver and comprehensive documentation
    Major Updates:
    - Refactored receiver into modular architecture for better maintainability
    - Added comprehensive README files for Transmitter and Receiver
    - Updated main README with detailed pin configurations and circuit diagrams
    - Documented all hardware connections with ASCII diagrams
    Transmitter Changes:
    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
2026-01-03 Update documentation with web flasher method and Home Assistant screenshots
    Major Documentation Updates:
    - Simplified FLASHING.md to focus on web-based flasher (esptool-js)
    - Added step-by-step instructions with screenshots
    - Removed complex CLI-only methods for better user experience
    Screenshots Added:
    ✅ docs/Selecting the board.jpg - Device selection in web flasher
    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
2026-01-03 Add hardware photos to all README files
    Hardware Photos Added:
    ✅ Transmitter image.JPG (5.2 MB) - Actual transmitter hardware photo
    ✅ Receiver Image.jpg (5.5 MB) - Actual receiver hardware photo
    Documentation Updates:
    - Main README.md: Added "Hardware Photos" section after system overview
    * Shows actual transmitter unit (battery powered)
    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
2026-04-16 feat: v2.0 rewrite - ESP-IDF firmware + TankSync PWA
    Complete rewrite from Arduino to ESP-IDF for both receiver and transmitter.
    Added TankSync PWA cloud dashboard with MQTT, push notifications, and QR linking.
    Firmware:
    - ESP-IDF v5.4 for both ESP32 DevKit and ESP32-C3 receivers
    - LoRa pairing protocol, OTA updates (WiFi + LoRa relay)
    - Captive portal with auto-redirect (iOS/Android/Windows)
    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
    [BOM.csv, partitions.csv]
2026-04-16 feat: add CI/CD deploy workflow and PostgreSQL cloud server
    - GitHub Actions deploys to DO droplet on push to pwa/
    - server-cloud/ contains PostgreSQL-based server (replaces SQLite for cloud)
    - package-cloud.json uses pg driver instead of better-sqlite3
    - .env.example updated with Resend, Turnstile, MQTT public host vars
2026-04-16 feat: MQTTS support + auto MQTT credential provisioning
    Firmware v2.2.0:
    - Add use_tls field to MQTT config (TLS via ESP-IDF cert bundle)
    - Auto-select port 8883 when TLS enabled
    - Web API /api/mqtt accepts use_tls parameter
    - Both ESP32 DevKit and C3 receivers updated
    Cloud:
    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
2026-04-16 fix: UI copywriting + iOS keyboard loop fix
    Copywriting:
    - "No Sites Yet" → "No Tanks Yet"
    - "Add Your First Site" → "Connect Your Tank"
    - "Switch Site" → "Switch Location"
    - "Sites" section → "Locations" in Settings
    - "Name Your Site" → "Name Your Location"
    - "devices" count → "tanks" count
    iOS PWA fix:
    - Fixed keyboard show/hide loop on login screen
    - Login container uses fixed positioning instead of min-h-screen
    - All inputs forced to 16px to prevent iOS auto-zoom
    - useEffect dependency fix to prevent re-render loop
2026-04-16 docs: add troubleshooting + self-hosting guide, remove old v1 images
    - Troubleshooting guide: receiver, transmitter, cloud, hardware issues
    - Self-hosting guide: SQLite quick setup + PostgreSQL production deploy
    - Removed legacy v1 images (BaudRate, circuit diagram, receiver gif)
2026-04-16 fix: iOS autofill/keyboard conflict on login form
    - Add autoComplete hints so iOS treats login vs register correctly
    - username/current-password for login, email/new-password for register
    - one-time-code for OTP input (triggers iOS code autofill from SMS/email)
    - form autoComplete=off in verify mode to prevent password bar
    - Removed autoFocus on OTP (was causing focus fights with iOS keyboard)
2026-04-16 feat: client-side QR claim — phone verifies receiver, not server
    The cloud server can't reach the receiver (different network). Moved
    the verification + device discovery to the phone (which IS on LAN):
    1. Phone verifies token with receiver directly
    2. Phone discovers tanks from receiver's /api/data
    3. Phone sends verified data to cloud server
    4. Server creates site + MQTT credentials
    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
2026-04-16 fix: in-app QR scanner redirects to LinkDevice for proper claim flow
2026-04-16 fix: handle mixed content (HTTPS→HTTP) in QR claim flow
    HTTPS pages can't fetch HTTP receiver APIs (browser blocks mixed content).
    - Tank discovery and MQTT push are now best-effort (fail silently)
    - Server no longer requires client-side verification — QR token URL
    is proof of physical access (only visible on receiver's screen)
    - If tank discovery fails, server creates empty site (user adds manually)
    - If MQTT push fails, success page shows manual config instructions
2026-04-16 feat: seamless QR claim — receiver serves redirect page
    QR code now points to http://<receiver-ip>/claim which:
    1. Collects tank data locally (same-origin HTTP, no mixed content)
    2. Redirects to https://tanksync.smartghar.org/link with tanks encoded in URL
    3. Cloud creates site + MQTT credentials
    4. Success page shows MQTT config (auto-push or manual instructions)
    This solves the HTTPS→HTTP mixed content issue that prevented
    the cloud page from talking to the local receiver.
    [web_server.c]
2026-04-16 fix: larger QR code (280px) + scanner URL trim + return guard
    [web_server.c]
2026-04-16 feat: add landing page with pricing, features, hardware kits
    Apple-style one-page landing for TankSync Cloud:
    - Hero with animated gradient + CTA
    - Problem stats (water waste, pump failures)
    - Solution with feature checklist
    - How it works (3 steps with placeholders)
    - 9-feature grid with hover animations
    - Tech specs for TX and RX
    - Pricing: Free/Home/Pro with auto INR/USD based on timezone
    - Hardware kits: Single (7,499) and Dual (11,999)
    - Footer with contact, GitHub, YouTube links
    Pricing (location-detected):
    - India: Free / ₹99/mo / ₹299/mo
    - International: Free / $1.99/mo / $4.99/mo
    Unauthenticated users see landing page at /.
    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
2026-04-16 feat(landing): SVG icons, water effects, dark mode fix, Pro pricing update
    - Replace all emoji icons with themed SVG icons (sky-400 stroke style)
    - Add animated water effects: floating bubbles, wave dividers, wave surfaces
    - Force dark mode on landing page (fixes light theme contrast issues)
    - Update Pro tier: ₹599/$9.99, cap at 10 sites/50 tanks (no unlimited)
    - Add CSS keyframes for bubble-rise and wave-drift animations
2026-04-16 refactor: remove cloud server, keep local-hostable PWA only
    Cloud PWA (server-cloud/, landing page, cloud CI/CD, cloud package files)
    moved to private repo. Public repo now contains only the
    self-hostable local PWA with SQLite backend + firmware + hardware docs.
2026-04-17 feat(config): TX config sync, robust OTA, improved device editor
    - Config retry: pending_config cleared only on SET_ACK receipt
    - OTA: move OTA_START to task (unblock rx_task), wait for OTA_DONE
    at SF7 before restoring SF9, skip OTA if TX already updated
    - Device editor: grouped sections (tank info, sensor calibration,
    transmitter settings), descriptive labels, read-only address,
    client-side validation
    - PWA: add sleep_s/samples to DB, API, edit form, and RX sync payload
    - Applied to both receiver (DevKit) and receiver-c3 (C3 Mini) variants
    [main.c, transmitter_registry.c, web_server.c]
2026-04-19 feat(rx): unique AP SSID + mDNS hostname, device_id in /api/system
    - AP SSID: TankSync-XXXX (last 4 hex of WiFi MAC) — multi-RX safe
    - mDNS hostname: tanksync-xxxx.local — unique per device
    - /api/system now returns device_id and mdns_host for PWA discovery
    - Added _tanksync._tcp mDNS service type for network discovery
    - Applied to both receiver (DevKit) and receiver-c3 (C3 Mini)
2026-04-27 docs(hardware): wiring diagrams, INA219 variant, MPPT solar charging
    Adds public/hardware/wiring.md as canonical pin/wiring reference for
    both RX targets (DevKit + C3 SuperMini) and TX with full solar power
    chain (CN3791 MPPT -> 18650 -> MT3608 boost -> 5V rail).
    Two TX power-monitoring variants documented:
    Variant A: voltage divider on ADC (legacy, simpler BOM)
    Variant B: INA219 over I2C (full charge/discharge/power telemetry)
    BOM.csv updated: replace TP4056 (linear) with CN3791 (MPPT) for solar
    use, add MT3608 boost, INA219, solar panel, protected 18650 holder.
    Two SKU totals: A and B.
    README.md hardware section now points to wiring.md prominently.
    [BOM.csv]
2026-04-27 feat(firmware): INA219 + voltage-divider auto-detect, power telemetry
    TX firmware 2.0.4, RX firmware 2.2.0 (DevKit + C3 SuperMini).
    Adds INA219 over I2C as Variant B alongside the existing voltage-
    divider Variant A. Boot-time I2C probe at 0x40 auto-selects the mode;
    NVS key 'pwr_mode_ovr' (auto/voltage/ina219/disabled) provides a
    manual override accessible via the wifi_ota web UI dropdown.
    TX:
    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
2026-04-27 docs(hardware): Mermaid circuit diagrams + wire-by-wire connection lists
    Adds GitHub-rendering Mermaid flowchart diagrams for:
    - Whole-system view (panel -> MPPT -> battery -> boost -> TX -> LoRa -> RX)
    - RX board (USB power, both DevKit and C3 SuperMini)
    - TX board (full power chain showing both Variant A and Variant B)
    Each board now has a 'Wire-by-wire' section that enumerates every
    solder/breadboard wire explicitly (e.g., 'C3 SuperMini GPIO1 -> INA219
    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
2026-04-30 docs(hardware): PCB design notes — buttons, level shifters, INA219 layout
    Augments the existing wiring reference for production PCB layout (vs
    breadboard prototyping). Three additions:
    1. User-interaction model section — both boards expose two physical
    buttons (BOOT for hold-2s pair / hold-5s AP-mode + RESET) and a
    status LED. Strapping-pin caveats called out for GPIO0 (RX) and
    GPIO9 (TX) so the dev-board's onboard pull-up + momentary press
    pattern is preserved.
    2. PCB-specific notes for TX — ECHO line voltage divider mandatory
    (5V → 3.3V via 1k+2k), antenna keep-out distances for RYLR998 +
    C3 PCB antenna, decoupling caps near each IC, 18650 reverse-
    polarity S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
2026-05-20 docs: troubleshooting — multi-hub same-location isolation explainer
    Adds a "I have multiple hubs at the same location — will they interfere?"
    Q&A that documents the three isolation layers (NETID + single-hub pair-
    mode + cloud topic scoping) and points users to PWA Settings → hub row
    to verify NETID for each hub. Aligns the public user-facing answer with
    the architecture shipped in rx-v2.7.13 + PWA 1.10.5.
2026-05-23 docs(hardware): document buzzer wiring + GPIO2 strapping caveat
    The buzzer feature (RX 2.8.0+) wires an active 3-pin buzzer to GPIO2
    on the DevKit ESP32 RX hub. Three additions to the canonical wiring doc:
    - Pin map table: new GPIO 2 row with strapping-pin caveat and OTA note.
    - Wire-by-wire: new BUZZER section with VCC/GND/SIGNAL connections.
    - Power notes: 3V3 rail now also feeds buzzer VCC alongside RYLR998 + OLED.
    The strapping caveat matters for new builders — if the buzzer signal
    wire is connected during USB flashing, the chip may stay in ROM
    download mode and never boot. Documented explicitly because it's the
    most likely "I wired it up but it won't boot" support question.
    S3 Supe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
2026-05-23 docs(hardware): add ESP32-S3 SuperMini RX wiring section
    Documents the newer S3 production board alongside DevKit ESP32 + C3
    SuperMini. Pin map + wire-by-wire list + buzzer entry (GPIO4, no
    strapping conflict — contrast with DevKit GPIO2). Notes the
    preprocessor-target build path (single Receiver-ESP32-DevKit source
    tree, esp32 vs esp32s3 switched via idf.py set-target).
    Closes the doc gap from the 2026-05-23 audit. Public builders on
    the S3 board now have a canonical wiring reference.
2026-05-23 docs(readme): announce buzzer alerts + sensor health safety nets
2026-05-23 docs: lead Quick Start with the browser flasher (Option 1)
    Surfaces tanksync.smartghar.org/firmware/ as the easiest path to flash —
    no esptool, no Python, no command line, just plug-and-flash via
    WebSerial on Chrome/Edge. Demotes esptool.py to Option 2 and source
    build to Option 3.
    Mentions the GPIO2 strapping caveat (disconnect buzzer signal wire
    before first-time USB flash on the ESP32 DevKit) and the CP2102 driver
    requirement up front so users don't run into either silently.
2026-05-23 chore: re-license firmware to AGPL-3.0, refresh from private source, remove pwa/
    Big release-prep cleanup. Three things in one commit because they all
    have to happen atomically for the public repo to be in a consistent
    state.
    1. LICENSE: MIT → AGPL-3.0 (firmware) + canonical CC-BY-SA 4.0 (hardware)
    - Firmware AGPL prevents commercial vendors from repackaging into
    closed products. Free for hobbyists, HA users, integrators —
    same as MIT was for them.
    - Hardware stays under CC-BY-SA, just upgraded to the canonical
    legalcode text (was abbreviated before).
    2. README: completely rewritten as TankSync's public face. Leads with
    the browser flasher (the easiest path), fr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
    [partitions.csv]
2026-05-23 fix: actually add firmware/ this time (.gitignore was swallowing it)
    Previous commit (aeb6c9b) successfully removed pwa/, swapped LICENSE
    to AGPL, and replaced README — but silently dropped the firmware/
    update because .gitignore had these unanchored patterns:
    Receiver-ESP32-DevKit/
    Receiver-ESP32-C3/
    Receiver-IDF/
    Transmitter-IDF/
    Those were added back in the old monorepo days when dev workspaces
    were cloned at the repo root (e.g., as Receiver-ESP32-DevKit/). They
    matched ANY directory of that name at ANY depth, including the
    firmware/Receiver-ESP32-DevKit/ tree the sync workflow was placing.
    Result: post-sync the repo had a `firmware/` reference but the
    directory tree was empty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
    [partitions.csv]
2026-05-23 docs(hardware): add full hardware reference + firmware screenshots
    One-time manual bootstrap from private dev repo. Future syncs flow
    automatically via the sync-to-public workflow on every rx-v* / tx-v*
    tag push (per RELEASES.md in private).
    Hardware additions:
    - hardware/README.md: overview with embedded photo gallery
    - hardware/pcb/: schematics (PNG + SVG), STEP 3D models, pin-assignments
    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
    [BOM.csv, base-holder.stl, bolt-screw.stl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]
2026-05-23 docs(readme): refresh hero with new PCB + case photos; move v1.0 images to legacy/
    Hero now shows the current production hardware:
    - pcb-populated-top.jpg (custom circular TX PCB)
    - case-side-profile.jpg (PETG enclosure, REV 2.2, 45°C-tested)
    Added a 'Photos of a real build' section with 6 more shots covering
    the build journey: bare PCB → populated → opened case → lid with solar
    → sensor mount → close-up of the threaded boss.
    Moved the v1.0-era images out of docs/images/ into docs/images/legacy/
    to preserve them without confusing new visitors:
    - receiver.jpg, transmitter.jpg (replaced by hardware/photos/case-*)
    - flashing.jpg, selecting-board.jpg (replaced by docs/firmware/scree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
2026-05-23 fix(readme): images broken — hero now points at hardware/photos/ (was docs/images/ which got moved to legacy/)
    Previous commit 1ee5f33 moved the old v1.0 images to docs/images/legacy/
    but the README still referenced docs/images/receiver.jpg + transmitter.jpg.
    Result: broken images at the top of the public repo's README.
    Fixed:
    - Hero now uses hardware/photos/pcb-populated-top.jpg + case-side-profile.jpg
    - Added "Photos of a real build" gallery section with 6 more shots
    Verified: all referenced paths return HTTP 200 from raw.githubusercontent.com.
2026-05-23 docs(readme): swap hero right image to the sensor-mount shot ci(release): recognize per-binary tag scheme (rx-v*, tx-v*, rxc3-v*)
    README:
    - Hero right image now shows case-sensor-mount.jpg (the BSP-threaded
    sensor screw mounted on a test tank lid) instead of case-side-profile.jpg.
    Per Ravi: "use the screw one image of 3D enclosure on README, not side
    view of the 3D cased product."
    CI:
    - build-firmware.yml previously triggered on 'v*' only and referenced
    outdated firmware/receiver/ + firmware/transmitter/ paths that don't
    exist on main. Updated to:
    - Trigger on rx-v*, tx-v*, rxc3-v* (matches the sync-to-public
    workflow in private)
    - Identify the target from the tag pr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
2026-05-23 sync(rx): rx-v2.8.5
    [BOM.csv]
2026-05-23 fix(post-sync): restore wiped public-only docs, un-flatten screenshots, restore hero swap
    The first auto-sync of rx-v2.8.5 had 3 bugs that this commit hand-corrects.
    The sync workflow has been patched too (see private repo) so the next
    sync doesn't reintroduce these.
    1. docs/ was wiped wholesale — restored:
    - docs/troubleshooting.md (the comprehensive symptom→fix reference)
    - docs/self-hosting.md (DIY broker walkthrough)
    - docs/images/legacy/ (v1.0-era pictures kept for posterity)
    2. docs/firmware/screenshots/ got flattened to docs/screenshots/ —
    moved back to the full path so all wiki + README image references
    resolve again.
    3. Hero right image in README was reverted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
